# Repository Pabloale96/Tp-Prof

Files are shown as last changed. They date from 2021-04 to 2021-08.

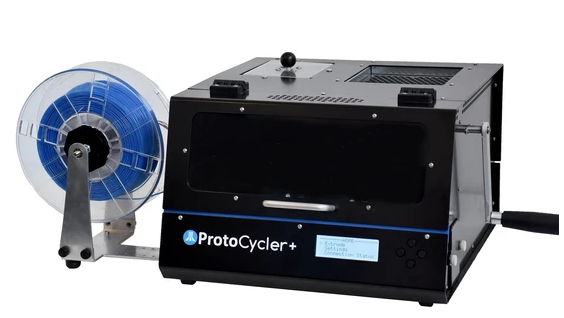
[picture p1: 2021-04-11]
Informacion-Equipos-Comerciales/redetec/producto.png

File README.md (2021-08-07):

# Trabajo Profesional

Este trabajo consiste en realizar una excursora de plastico, principalmente del polimero PLA que es el mas usado en las impresoras 3D. Dicho polimero empiza a ser moldiable en una temperatura entre los *80 ºC* a *110 ºC*, para realizarlo vamos a realizar un control de temperatura sobre el extrusor para mantener una temperatura en ese rango. Vamos a considerar que el plastico ingresa en trozos iguales y de un tamaño entre *1.5 mm* a *2.5 mm* **(Le tire para tirar)**. 

## Distribución del git (carpetas):

    - **Archivo README.md**: es lo que lees en el git, siempre que agregues alguna informacion intenta de agregarlo aca.
    - **Bibliografia**: carpeta en donde guardaremos toda la informacion de otros utilizada para poder realizar el proyecto, es importante agregar todo lo que usamos hasta los link de iterner, despues en el informe final seguro haya que agregarlo, creare un archivo de *link.txt* para todo el tema de los links, si se puede agregar una mini descripcion.
    - ** Diseño **: esta carpeta se divide entre las diferentes etapas del proyecto siguiendo la forma
    - ** Etapa1-Extrusora**: carpeta que contiene la informacion sobre la etapa de la extrusora, se divide de la forma:
        - ** Componentes **: aca se colocara la informacion de los componentes mecanicos y electricos usado en la etapa
        - ** Diseño **: carpeta que contiene el todos los datos sobre el diseño de la etapa, como por ejemplo, circuitos, modelos 3D, plano
        - ** Firmware **: carpeta que contiene el codigo del microcontrolador de la etapa
    - ** Etapa2-PID-Temp**: carpeta que contiene la informacion sobre la etapa del control de temperatura, se divide de la forma:
        - ** Componentes **: aca se colocara la informacion de los componentes mecanicos y electricos usado en la etapa
        - ** Diseño **: carpeta que contiene el todos los datos sobre el diseño de la etapa, como por ejemplo, circuitos, modelos 3D, plano
        - ** Firmware **: carpeta que contiene el codigo del microcontrolador de la etapa
    - ** Etapa3-Enfriamiento**: carpeta que contiene la informacion sobre la etapa del enfriamiento a la salida de la extrusora, se divide de la forma:
        - ** Componentes **: aca se colocara la informacion de los componentes mecanicos y electricos usado en la etapa
        - ** Diseño **: carpeta que contiene el todos los datos sobre el diseño de la etapa, como por ejemplo, circuitos, modelos 3D, plano
        - ** Firmware **: carpeta que contiene el codigo del microcontrolador de la etapa
    - ** Etapa4-Diametro-Medicion**: carpeta que contiene la informacion sobre la etapa de medicioin de diametro sin contacto, se divide de la forma:
        - ** Componentes **: aca se colocara la informacion de los componentes mecanicos y electricos usado en la etapa
        - ** Diseño **: carpeta que contiene el todos los datos sobre el diseño de la etapa, como por ejemplo, circuitos, modelos 3D, plano
        - ** Firmware **: carpeta que contiene el codigo del microcontrolador de la etapa
    - ** Etapa5-Bobinado**: carpeta que contiene la informacion sobre la etapa del bobinamo del material reciclado, se divide de la forma:
        - ** Componentes **: aca se colocara la informacion de los componentes mecanicos y electricos usado en la etapa
        - ** Diseño **: carpeta que contiene el todos los datos sobre el diseño de la etapa, como por ejemplo, circuitos, modelos 3D, plano
        - ** Firmware **: carpeta que contiene el codigo del microcontrolador de la etapa
    - ** Etapa6-Tablero**: carpeta que contiene la informacion sobre la etapa del diseño del tablero para el uso de la maquina, se divide de la forma:
        - ** Componentes **: aca se colocara la informacion de los componentes mecanicos y electricos usado en la etapa
        - ** Diseño **: carpeta que contiene el todos los datos sobre el diseño de la etapa, como por ejemplo, circuitos, modelos 3D, plano
        - ** Firmware **: carpeta que contiene el codigo del microcontrolador de la etapa
    - ** Factibilidad-Gestion-Tareas ** : carpeta que presenta el analisis realizado del mercado junto con las cantidad de hora de cada tarea, dentro se devide en la parte de factibilidad y la parte de tareas.
    - ** Firmware **: carpeta donde presenta el codigo unido de las diferentes etapas.
    - ** Informacion-Equipos-Comerciales **: carpeta para guardar la informacion sobre los equipos comerciales que se encuentra en el mercado actualmente (competenecia)
    - ** Investigacion **: carpeta para guardar la investigacion sobre las normas necesarias para el comercio del producto
    - ** Reuniones **: carpeta donde se guardan las notas de las reuniones que se tuvieron con los tutores. Dentro se dividira en carpetas con un nombre año-mes-dia que se obtuvo la reunion

# Overleaf:
    -link : https://www.overleaf.com/project/60784f0907656d9d9f60732d

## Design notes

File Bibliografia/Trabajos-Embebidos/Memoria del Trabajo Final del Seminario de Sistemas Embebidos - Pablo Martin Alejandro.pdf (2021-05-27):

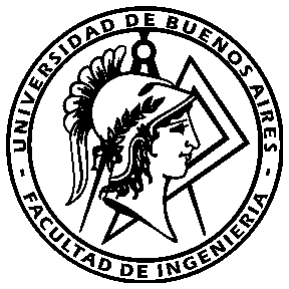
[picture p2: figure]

UNIVERSIDAD DE BUENOS AIRES Facultad de Ingeniería
Seminario de Sistemas Embebidos

Memoria del Trabajo Final:

## Reciclador PLA

Autor:

## Sr. Pablo Martín Alejandro

Legajo: 98.021

Este trabajo fue realizado en las Ciudad Autónoma de Buenos Aires, entre agosto y diciembre de 2019.

Memoria del Trabajo Final del Seminario de Sistemas Embebidos Sr. Pablo Martín Alejandro

## RESUMEN

En este trabajo se realizó el diseño y la fabricación de una recicladora de plástico PLA para el uso en la impresión 3D. La recicladora consiste en un sensor de temperatura con un control de completar, junto con un display para mostrar por pantalla un menú. También se agregó un módulo de wifi junto con un diseño de pagina web para el manejo de la misma. Se pudo aprovechar la herramienta de Yakindu para la realización del trabajo.

Martín Alejandro

## Índice General

Registro de versiones | 4

Introducción General

1.1 Descripción del proyecto | 5
Introducción Específica | 7
2.1 Descripción del hardware | 7
2.1.1 Plataforma de desarrollo | 8
2.1.2 Módulo Wifi | 9
2.1.3 Display y encoder | 10
2.1.4 Resistencia Cartucho | 10
2.1.5 Otros | 11
2.2 Descripción del software | 11
Diseño e Implementación | 13
3.1 Análisis del hardware | 13
3.1 Análisis del software | 15
Ensayos y Resultados | 19
4.1 Pruebas funcionales del hardware | 19
4.1 Pruebas funcionales del software | 19
4.1 Union del proyecto | 20
Conclusiones | 22
5.1 Conclusiones generales | 22
5.2 Próximos pasos | 22
Bibliografía | 23

Martín Alejandro

## Registro de versiones

Revisión | Cambios realizados | Fecha
1.0 | Creación del documento | 5/12/2019
1.1 | Correcciones del presente informe | 9/12/2019
1.2 | Continuación de correcciones | 10/12/2019
1.3 | Correcciones | 11/12/2019

Martín Alejandro

## CAPÍTULO 1

## Introducción general

### 1.1 Descripción del trabajo

El esquema general un reciclador de plástico PLA se puede observar en la figura 1.1. El reciclador tiene diferentes partes bien diferenciadas, como un calentador para lograr una temperatura fija en un extremo de la máquina. Otra parte es el motor de continua encargado de entregar el torque a una mecha de madera para trasladar el plástico. Por otro, lado, se usa un cilindro con una mecha de madera para trasladar el plástico depositado en la tolva, y con el torque de motor de continua se traslada al extremo caliente del cilindro. Por último, se coloca un pico fino para dar un diámetro al filamento que se extrae.

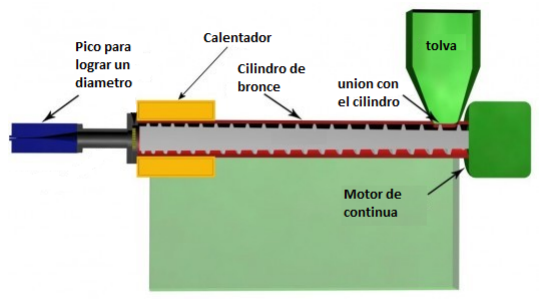
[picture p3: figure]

Figura 1.1: Partes del reciclador PLA

La recicladora PLA tiene ventajas tanto para las industrias como para personas en sus hogares. También ayuda para reducir desechos en el medio ambiente. Puede usarse tanto en la industria como en una casa, ya que recicla las partes de plástico que se consideran desecho, reduciendo la basura generada y lograr ahorrar dinero en materiales.

Martín Alejandro

El diagrama en bloques del sistema se muestra en la figura 1.2.

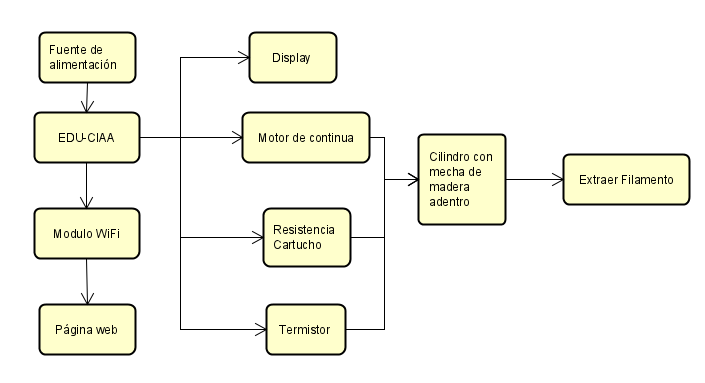
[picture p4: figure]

Figura 1.2: Diagrama de bloques del sistema.

Martín Alejandro

## CAPÍTULO 2

## Introducción específica

### 2.1 Descripción del hardware

En esta sección, se explica la fabricación del hardware del equipo. Para la realización del trabajo se colocó una mecha de madera (con la punta cortada) dentro de un cilindro hueco de bronce de igual diámetro para evitar que la mecha se atorre a la hora de trasladar el plástico (en nuestro caso se pidió utilizó un cilindro y una mecha de un diámetro de ⅝ de pulgada).

Se necesito fijar la estructura por el torque que generaba el motor sobre la misma. Se usaron para esto tornillos y una madera. Se utilizó un motor de continua para generar un torque sobre la mecha de madera, con esto se logra trasladar el plástico desde un punto A a un punto B.

Se conectó un driver (entre el motor y la EDU-CIAA) para el manejo de la corriente que necesita el motor de continua. Para el sensado de temperatura, se usó un termistor que varía su resistencia dependiendo de la temperatura. Para poder medir una temperatura de 200 ºC, se colocó una resistencia aproximada al valor del termistor en esa temperatura (500 ohm). En el programa, se empieza a medir a partir de 150 ºC que es lo que llega a medir el termistor con una resistencia aproximada de 500 ohm conectada en serie. Se colocó un display conectado a la EDU-CIAA donde se muestra el menú del equipo (para setear la temperatura y mover el motor a partir de un encoder). También se le agregó un módulo de WiFi donde se programa una página web para setear y mostrar los valores de temperatura y revisar si el motor de continua está prendida o no.

Para la colocación del plástico, se usó un material impreso por una impresora 3D al igual que la pieza que una el motor con la mecha y la que fija el motor a la madera. Todo lo mencionado anteriormente se observa conectado en la figura 2.1

Martín Alejandro

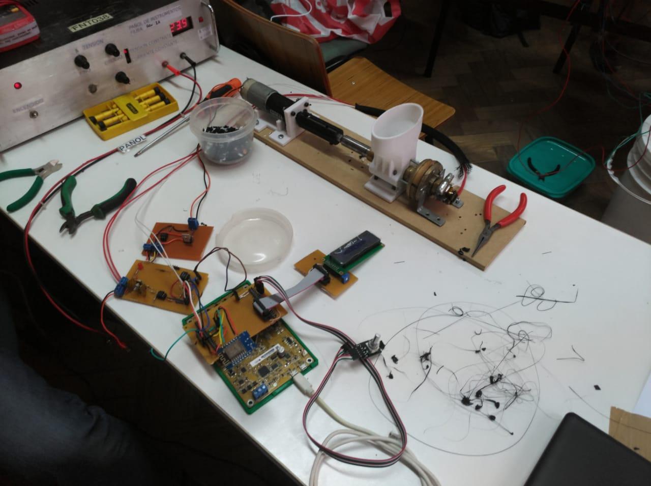
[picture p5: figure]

Figura 2.1:Reciclador Pla terminado.

### 2.1.1 Plataforma de desarrollo

La figura 2.2 muestra la placa EDU-CIAA la cual fue utilizada para la comunicación entre los diferentes equipos para el presente trabajo. La misma presenta toda la información de forma libre en internet en su página oficial [2]. Presenta un conversor DAC y un ADC, en este trabajo se realizó una medición usando el ADC de la placa, luego se comunicó con el puerto serie.

Martín Alejandro

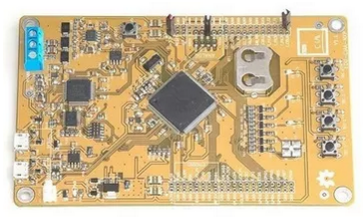
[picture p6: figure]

Figura 2.2: Placa EDU-CIAA.

### 2.1.2 Módulo de WiFi

Para la comunicación con la página web, se usó un módulo WiFi. En la figura 2.3 se observa dicho módulo, su modelo es el ESP8266. El mismo se comunica por puerto serie a la plataforma de desarrollo y luego actualiza los datos de la página web.

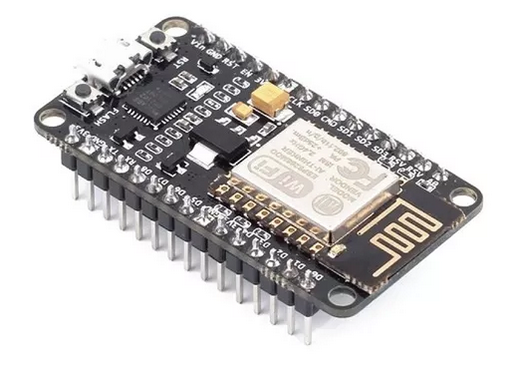
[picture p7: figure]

Figura 2.3: Módulo Wifi

Martín Alejandro

### 2.1.3 Display y Encoder

Para el manejo del trabajo, se realizó un menú para controlar los diferentes parámetros. Se usó un display común para visualizar dicho menú y un encoder común para controlar el menú. Las figura 2.4 y 2.5 muestran los dispositivos.

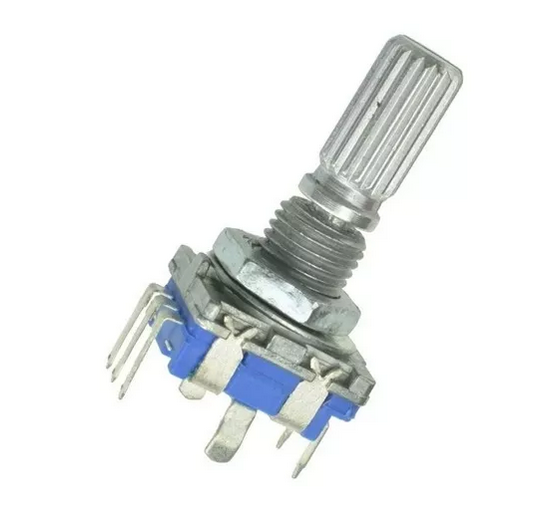
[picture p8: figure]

Figura 2.4: Encoder.

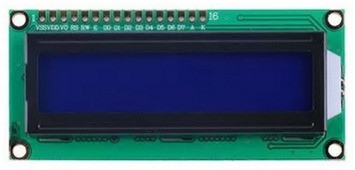
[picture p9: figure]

Figura 2.5: Display.

### 2.1.4 Resistencia cartucho

Para lograr calentar el extremo del tubo, se utilizó una resistencia cartucho conectada a 24 V. Se usó el PWM de la placa EDU-CIAA para reducir el valor rms de tensión sobre la

Martín Alejandro

resistencia cartucho (si se reduce la tensión calienta menos) para controlar la temperatura. La resistencia se muestra en la figura 2.6.

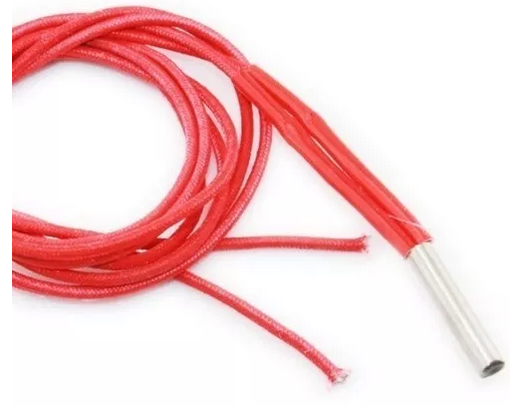
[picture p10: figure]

Figura 2.6: Resistencia Cartucho.

### 2.1.5 Otros

La medición de la temperatura se realizó con un termistor (resistencia que varía con la temperatura) ntc de valor nominal 100 kohm. Otros elementos fueron transistores para los circuitos usados como driver y controlador de la resistencia cartucho.

### 2.2 Descripción del software

El software se diseñó a partir de la herramienta de Yakindu, la cual permite usar un diagrama UML de máquinas de estado y luego genera un código que corresponde al diagrama realizado[1]. La idea lógica del programa es realizar un control de temperatura para lograr establecer un valor de 200 ºC en un extremo de la máquina, luego decirle al reciclador de mover el motor en para llevar el plástico al extremo caliente. El programa manda los datos a través de un módulo de Wifi a una página web mencionada anteriormente (también se puede setear la temperatura y activar el movimiento de motor desde ahí).

Se agregó un display por si el módulo o la página web no funciona para activar la máquina, el display muestra un menú que tiene la configuración de temperatura y motor. También tiene un menú de WiFi que muestra la IP de la página web.

Martín Alejandro

La figura 2.7 muestra la lógica del programa implementado.

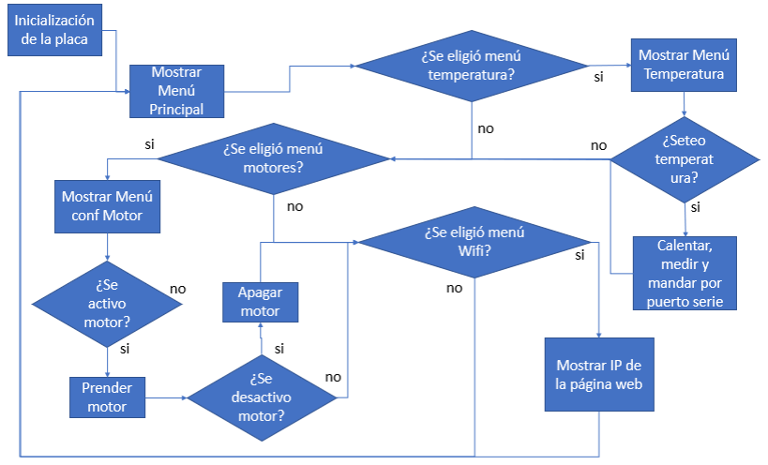
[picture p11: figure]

Figura 2.7 : Diagrama lógico del programa.

Martín Alejandro

## CAPÍTULO 3

## Diseño e implementación

### 3.1 Análisis del hardware

A la hora de realizar el trabajo, se consideró como principal problema la estructura por su partes mecánicas y la precisión milimétrica, la velocidad del movimiento del motor y la instalación de una resistencia cartucho junto con el termistor. Esta última, se debe a que la resistencia cartucho está a una temperatura mayor y para lograr medir la temperatura del cilindro, se necesita que el termistor este distante a la resistencia cartucho pero en contacto con el cilindro.

Para la conexión del motor, se usó un driver para aumentar la corriente que entrega la EDU-CIAA sobre el motor (usando una fuente de tensión de 24V). En la figura 3.1, se observa el circuito utilizado como driver.

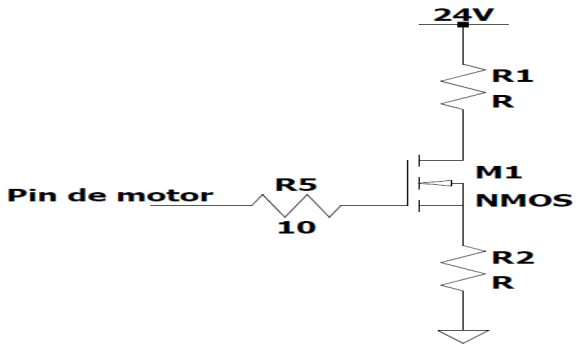
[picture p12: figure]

Figura 3.1: Circuito driver para el motor de excursión.

Por otro lado, para el control de la resistencia cartucha se usó el circuito de la figura
3.2. En la figura 3.3, se muestra el circuito usado para la medición de la temperatura a

Martín Alejandro

través del termistor, teniendo en cuenta la ecuación de resistencia de un termistor, presentada a continuación como:

R = R | | (3.1)
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
en donde se puede despejar la temperatura. Resolviendo el circuito de la figura 3.3 se puede llegar a un valor de R como:

R = 500 oℎm | , | (3.2)

V

CC−V
ADC
V
ADC
usando la EDU-CIAA se mide la tensión sobre el pin de ADC y luego se despeja la resistencia R, luego se puede despejar la temperatura teniendo en cuenta los parámetros dado por el fabricante[4]. Realizando todo lo mencionado, se puede aproximar la relación tensión temperatura con la siguiente fórmula:
T = | .

129.3*1000+V
ADC

*34.5

1000

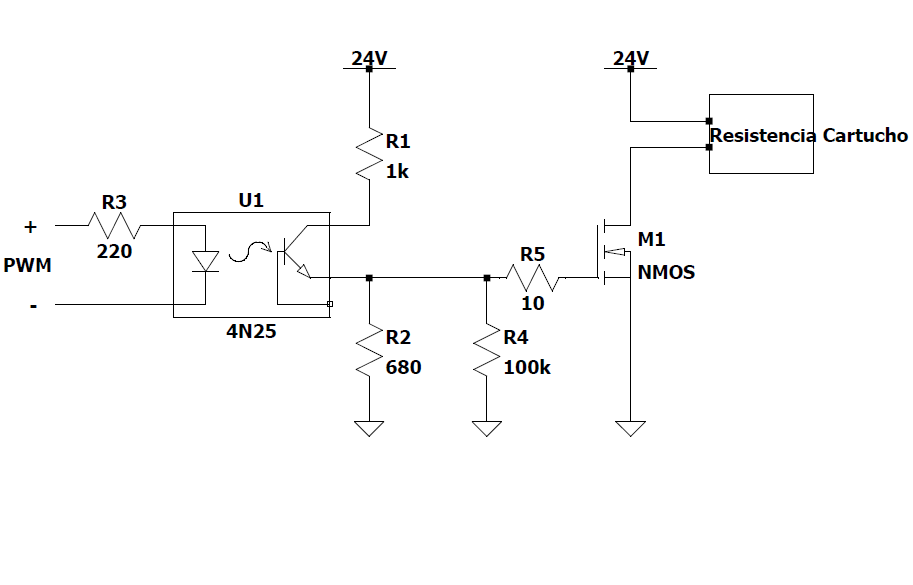
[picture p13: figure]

Figura 3.2: Circuito de control de la resistencia Cartucho.

Martín Alejandro

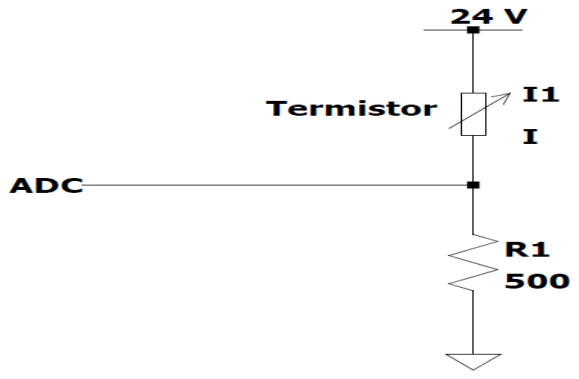
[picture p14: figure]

Figura 3.3: Circuito para la medición de la temperatura.

### 3.2 Análisis del software

El software fue generado a partir un diagrama UML de estados a partir de la herramienta de Yakindu. Por motivos de complejidad, se decidió dejar el link del repositorio de GitHub[3] usado para el trabajo práctico ya que el diagrama de estados es demasiado grande para mostrar una imagen.

Igualmente, se mostrará la complejidad del diagrama de estados con las figuras 3.4 hasta la figura 3.9 . El archivo prefix usado en Yakindu es demasiado largo para mostrar en una imagen por lo que no se incluye.

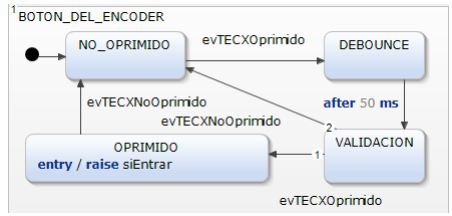
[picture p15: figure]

Figura 3.4: Diagrama de estados para controlar el botón oprimido.

En la figura 3.4, se muestra un diagrama de estado para la validación de un pulsador (el presente en el encoder) .

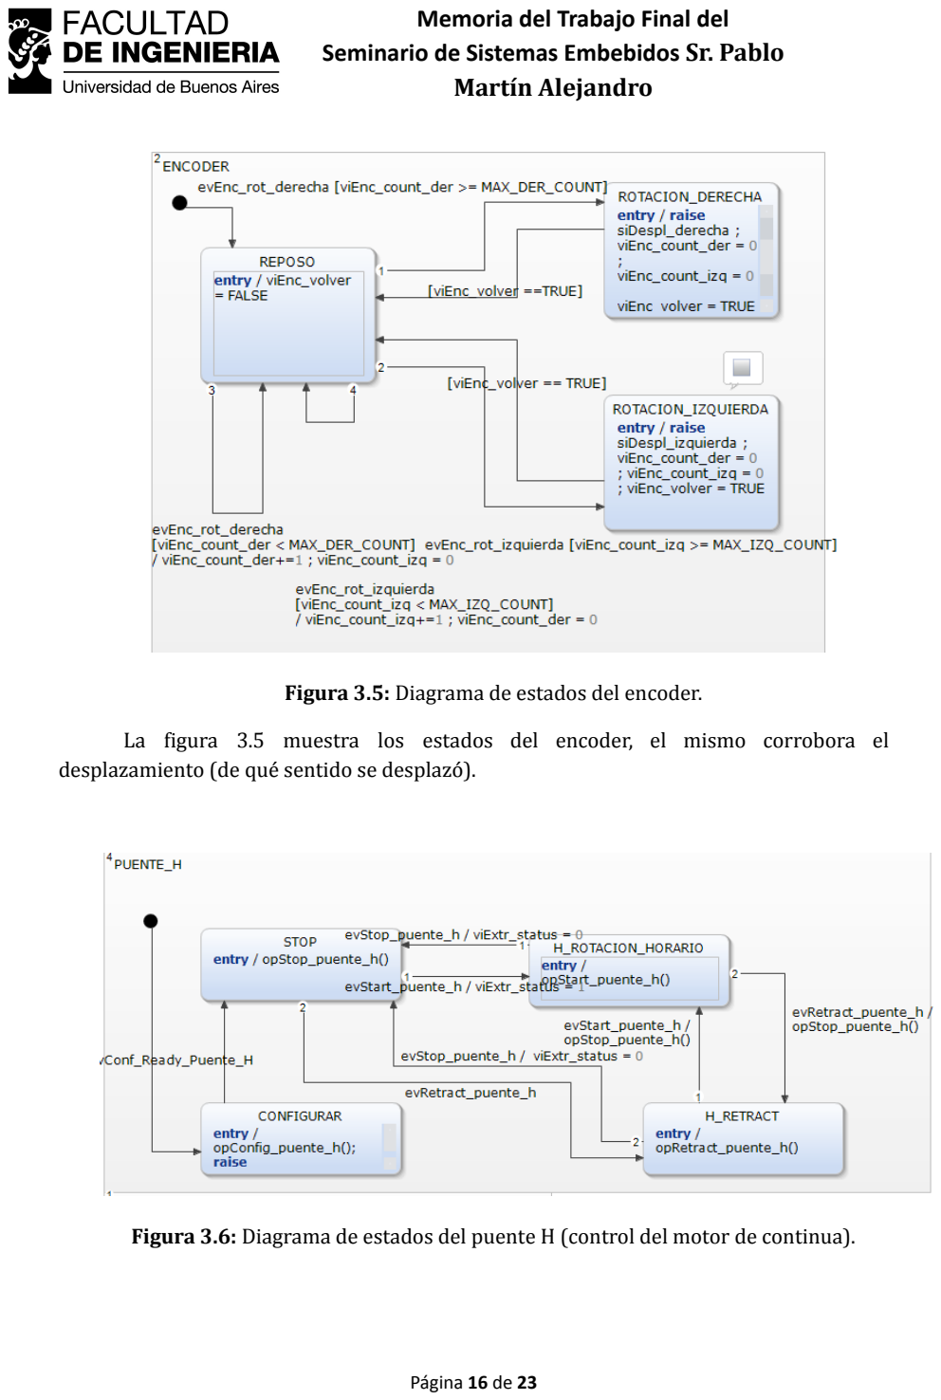
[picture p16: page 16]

Martín Alejandro

Figura 3.5: Diagrama de estados del encoder.

La figura 3.5 muestra los estados del encoder, el mismo corrobora el desplazamiento (de qué sentido se desplazó).

Figura 3.6: Diagrama de estados del puente H (control del motor de continua).

Martín Alejandro

El control del motor se realiza con el diagrama de estado de la figura 3.6. Se observa 4 estados, en donde el estado inicial es de la configuración los pines gpio de la EDU-CIAA. Los otros 3 estados setean el estado del motor (apagado, encendido o reversa).

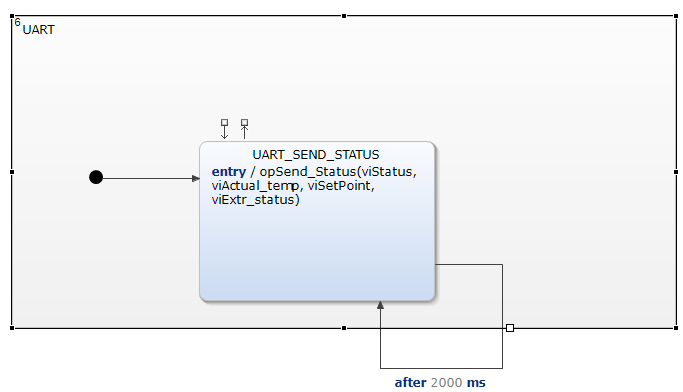
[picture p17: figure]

Figura 3.7: Diagrama de estados del envío de mensajes por UART.

El envío por UART presenta un solo estado que se repite cada 2 segundos, esto se observa en la figura 3.7.

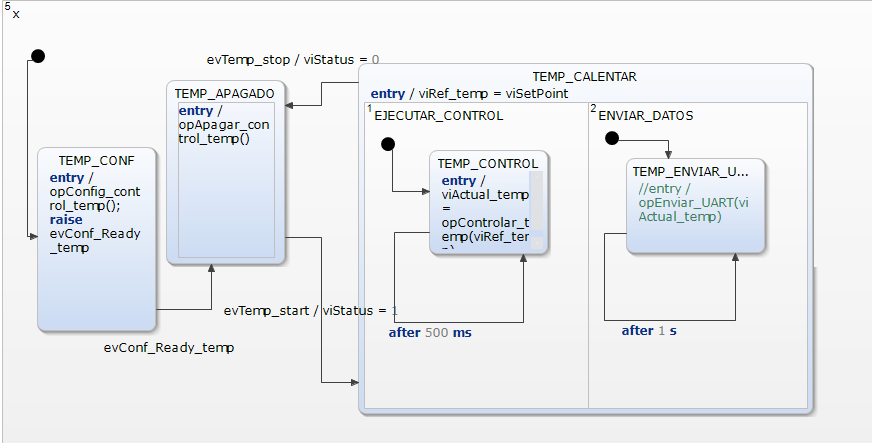
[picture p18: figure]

Figura 3.8: Diagrama de estados sensado y control de temperatura.

Para el control de temperatura se observa un estado inicial que sirve para la configuración del ADC. Luego, se mantiene en un ciclo entre los estados de apagado de la

Martín Alejandro

temperatura (al inicio la máquina no realiza nada) y un estado compuesto que realiza un control de temperatura y envía los datos por puerto serie.

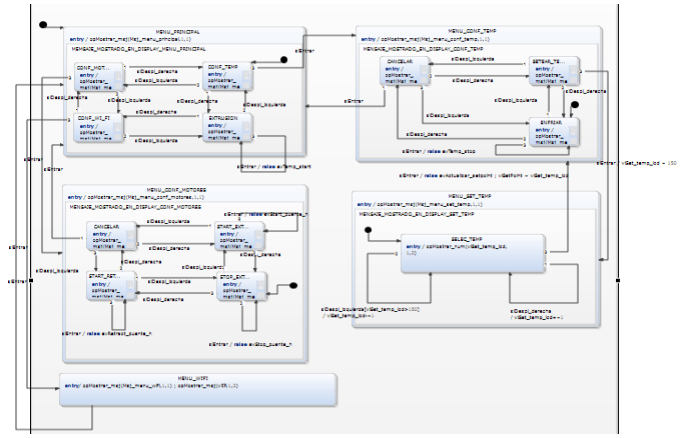
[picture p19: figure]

Figura 3.9: Diagrama de estados del menú.

Por último, en la figura 3.9 se observa los estados del menú realizado. El mismo consta con un menú principal que se divide en 3 submenus.

Martín Alejandro

## CAPÍTULO 4

## Ensayos y resultados

### 4.1 Pruebas funcionales del hardware

La primera prueba realizada sobre el trabajo es comprobar el funcionamiento correcto de la partes mecánicas armadas. Para eso, se armó el producto y manualmente se revisó el funcionamiento de la mecánica.

La segunda prueba incluyó agregar el motor de continua para poder revisar la velocidad y el movimiento a esa velocidad. En esta prueba, se encontró un problema con el torque generado por el motor, el mismo provocaba que la piezas de plástico se rompieran por un giro inesperado sobre ellas (las piezas giraban con la mecha). La solución a este problema fue atornillar las piezas a un bloque de madera.

Por último, se probó el correcto calentamiento del extremo del cilindro revisando el circuito mencionado en la figura 3.2. Se colocó la resistencia cartucho y se utilizó una señal de pwm constante para controlar a qué temperatura aumenta. Luego, se varió el pwm para ver cómo modifica la temperatura. La figura 2.1 muestra la mecánica del reciclador completo, mientras la figura 4.1 muestra una de las uniones de la mecánica (la mecha de madera con el motor de continua).

### 4.2 Pruebas funcionales del software

La primera prueba tenía que ver con el control y sensado de la temperatura. Para eso se midió la temperatura a través del ADC (como se mencionó anteriormente) y luego se aplicó una planta para lograr aumentar la temperatura al menor tiempo posible sin pasarse del valor establecido. Con la medición de la temperatura mencionada anteriormente, se mandó el valor al puerto serie para visualizar en la computadora.

La segunda prueba era controlar que el valor de la temperatura medida con el termistor es la equivalente en la punta. Para eso, se usó un multímetro con una termocupla en sus terminales (con la capacidad de medir grados ºC) y se revisó que el valor del multímetro sea el mismo con el medido en el termistor. La figura 4.2 muestra lo que se recibió la computadora por puerto serie en una terna donde indica si la temperatura está prendida (ON/OFF). El segundo valor indica la temperatura medida por

Martín Alejandro

el termistor (un valor numérico). El último carácter indica la temperatura a la que se tiene que llegar (otro valor numérico). La terna está separado por el caracter ‘ , ’.

Por último, se probó el módulo de WiFi desconectado con el resto de las placa y controlamos si actualizaba la página web. Para comprobar el correcto funcionamiento, se transmitió por puerto serie los valores random hacia el módulo de Wifi y luego se actualizaba la página web.

### 4.3 Unión de las partes del reciclador

La última prueba de todas fue comprobar el conjunto de las partes de la máquina. Se comprobó, principalmente, las partes por separados. Realizando la unificación de todas las partes y se logrando reciclar plástico triturado. La figura 4.3 muestra el filamento extraído por el reciclador.

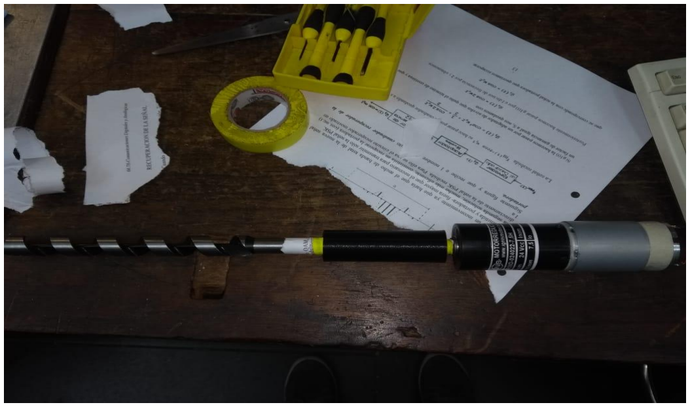
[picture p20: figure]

Figura 4.1: Unión de la mecha con el motor de continua.

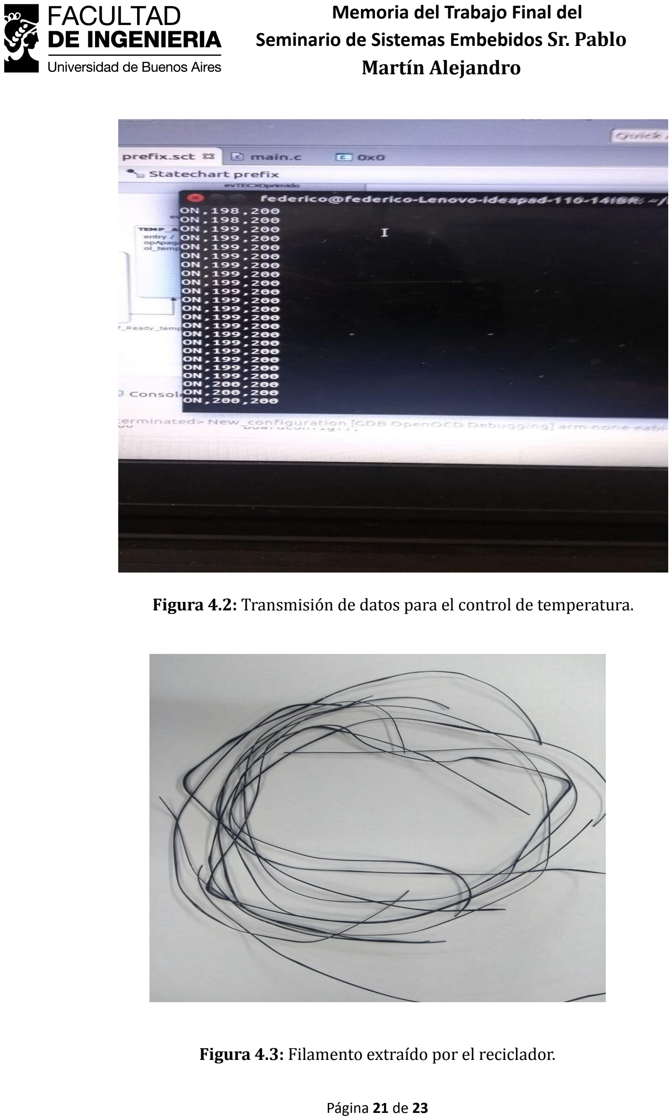
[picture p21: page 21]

Martín Alejandro

Figura 4.2: Transmisión de datos para el control de temperatura.

Figura 4.3: Filamento extraído por el reciclador.

Martín Alejandro

## CAPÍTULO 5

## Conclusiones

### 5.1 Conclusiones generales

La principal conclusión se consigo en la facilidad de hacer diagramas de estados a través de la herramienta Yakindu, la misma define estados, variables y operaciones que luego en el código se editan para realizar la tarea que uno decide hacer (creo funciones con sus argumentos y variables globales que luego en el código se puede definir dichas funciones).

Otra conclusión importante es la división de tareas formado por el equipo de trabajo, sin una planificación (informe de planificación) previo nos dio la pauta para lograr el trabajo en el tiempo determinado, o por lo menos lograr una presentación prolija y tener documentación sobre el trabajo.

Finalmente, realizar una tarea de mecánica avanzada puede generar problemas a futuro si es que no se tuvo en cuenta en el informe de planificación del trabajo com un riesgo posible.

### 5.2 Próximos pasos

El trabajo tiene varias mejoras, en esta sección se mencionan algunas:

- Lograr un diámetro constante a través de una rueda hueca y una rueda plana para darle forma de cilindro al filamento de salida con un diámetro determinado.
- Enrollar el filamento de salida del trabajo en un cilindro de plástico para luego usar directamente con la impresora 3D.
- Conseguir una trituradora de plástico para lograr problema de tamaño
- Enfriar el filamento de salida a una velocidad que permite enrollar el filamento a la salida del proceso.
- Diseñar una fuente de tensión continua para conectar a la red directamente.

Martín Alejandro

## Bibliografía

[1] YAKINDU(2016, Jun 26). YAKINDU Documentation [Online]. Available: https://www.itemis.com/en/yakindu/state-machine/
[2] Proyecto CIAA (2016, Jun 26). EDU-CIAA-NXP [Online]. Available: http://www.proyecto-ciaa.com.ar/devwiki/doku.php
[3] Repositorio del trabajo final usado. Available:

https://github.com/Federiconunezfrau/Reciclador_PLA.git

[4] Hoja de datos del termistor. Available:

Buscar en google “NTC Thermistor Farnell datasheet” y descargar el pdf

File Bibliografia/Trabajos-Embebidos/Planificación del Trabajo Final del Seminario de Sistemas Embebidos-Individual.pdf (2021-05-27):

### Plan del Trabajo Final de Sistemas Embebidos Pablo Martin Alejandro-Padrón 98.021

# Reciclador de PLA

### Autores

## Pablo Martin Alejandro-Padrón 98.021

### Fecha:

## 2do cuatrimestre 2019

### Tabla de contenido

Registro de cambios | 3
Descripción técnica-conceptual del proyecto a realizar | 4
Acta de constitución del proyecto | 5
1. Propósito del proyecto | 6
2. Alcance del proyecto | 6
3. Supuestos del proyecto | 6
4. Requerimientos | 6
5. Entregables principales del proyecto | 7
6. Desglose del trabajo en tareas | 7
7. Diagrama de Gantt | 7
8. Gestión de riesgos | 8
9. Gestión de la calidad | 9

### Registro de cambios

Revisión | Cambios realizados | Fecha
1.0 | Creación del documento y firma del Acta de Constitución | 17/09/2019
1.1 | Completación de la descripción técnica-conceptual del proyecto | 17/9/2019
1.2 | Realización de las secciones 1,2,3,4,5,6,y mitad del 8 | 24/9/2019
1.3 | Correcciones de las secciones mencionadas y realización de las secciones 7,8 y 9. | 30/9/2019
1.4 | Correcciones del informe en general | 1/10/2019

### Descripción técnica-conceptual del proyecto a realizar

En este proyecto se propone construir un dispositivo automático que, a partir de restos plásticos de impresiones 3D (material PLA), produzca rollos de filamento nuevos que se puedan usar para imprimir nuevas piezas.

El hecho de poder generar filamento para impresión 3D a partir de restos de plástico tiene como motivación:

- El ahorro en el costo de compra de rollos de plástico nuevos.
- La contribución al cuidado del medio ambiente, dándole un nuevo uso a estos plásticos que fueran a ser desechados.

Para poder explicar el proyecto, se muestra en la Figura 1, las partes que lleva un reciclador PLA. Se tiene un Hopper para colocar el plástico a reciclar (el cual tiene que estar triturado), un Scew para trasladarlo hasta el Heater que presenta un Breaker plate para darle la forma correspondiente al plástico,.l Heater es el encargado de calentar el PLA hasta una temperatura que sea moldeable el mismo (la temperatura debe estar entre los 190ºC y 220ºC). Luego se da la forma de un cilindro con un diámetro de 1.75 mm (estándar que usan las impresoras 3D).

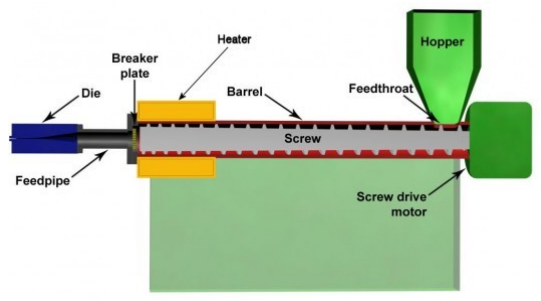
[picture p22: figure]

Figura 1.Partes del reciclador PLA

El proceso de extrusión se puede observar en la Figura 2. El mismo se considera un Extruner que sería la parte mecánica mostrada en Figura 1, a la salida del mismo un proceso de enfriado para poder dejar el plástico firme. Luego se realiza un pulido del mismo a través del Puller y por último se enrolla el filamento en un cilindro en la parte de Cutting/Removal.

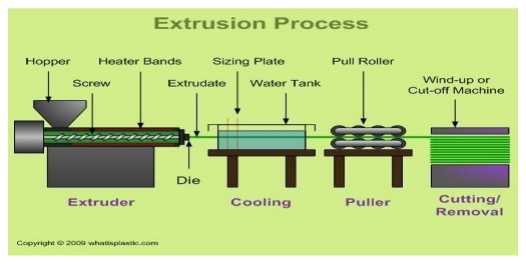
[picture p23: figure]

Figura 2:Proceso de excursión.

Para realizar el proyecto, se utiliza la placa de la EDU-CIAA para realizar el control de temperatura del dispositivo. Además se comunica el microcontrolador de la placa con un driver de motor para manejar tanto el motor que se utiliza para el Screw como el ventilador que enfría el plástico a la salida del extrudate. Para mostrar el uso de la EDU-CIAA se realizó un diagrama en bloques que se muestra en la Figura 3, donde el motor corresponde a la traslación del plástico del punto inicial hasta el punto donde se moldea el plástico, es decir, hasta el heater bands el cual se encuentra representado con el bloque “control de temperatura”. A la salida del mismo, se va a encontrar el filamento a una temperatura aproximadamente de (190-220)ºC estable en un rango de 5ºC para lograr moldear el plástico PLA, por lo tanto se coloca un ventilador y un motor paso a paso para enfriar el filamento y recolectar en forma de cilindro como se mostró anteriormente.

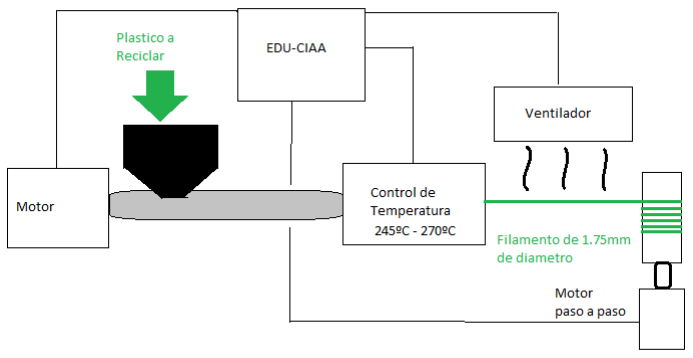
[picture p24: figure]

Figura 3:Diagrama de Bloques.

Con todo este sistema, se cumple el objetivo de lograr una recicladora de plastico PLA. Si sobra el tiempo se podría mejorar el equipo con:

1. Agregar display para marcar la temperatura.
2. Controlar diferentes temperaturas (esto lograría una gran mejora, ya que se podría utilizar para diferentes tipos de plástico, como el ABS).
3. Agregar una trituradora con un sistema de seguridad propio, ya que el plástico tiene que estar triturado para colocar en el sistema.

### Acta de constitución del proyecto

Buenos Aires, 24 de septiembre de 2019

Por medio de la presente se acuerda con el Alejandro, Pablo Martín que su Trabajo Final del Seminario de Sistemas Embebidos se titulará “Reciclador Pla”, consistirá esencialmente en el prototipo preliminar de un control de temperatura con un rango de 5ºC con un sistema embebido, y tendrá un presupuesto preliminar estimado de 140 hs de trabajo y $30000, con fecha de inicio lunes 14 de octubre de 2019 y fecha de finalización miércoles 4 de diciembre de 2019.

Se adjunta a esta acta la planificación inicial.

Ariel Lutenberg
Profesor Adjunto del Seminario de Sistemas Embebidos

### 1. Propósito del proyecto

El propósito de este proyecto es el diseño y la implementación de un “Reciclador PLA”, el cual cumple con la función de tomar plástico desechable y transformarlo en filamento para la impresión 3D que cada día se utiliza más. Una importancia del reciclado del plástico es evitar generar basura para mejorar el medio ambiente, aparte se podría ahorrar dinero en los filamentos generados.

### 2. Alcance del proyecto

El presente proyecto incluye las siguientes especificaciones:

- Terminar el proyecto antes de la fecha estipulada.
- Lograr generar un filamento utilizable para impresión 3D de diámetro de 1,75 mm.
- Conseguir un control de temperatura entre (190-220)ºC para el plástico PLA.
- Agregar opciones de conectividad: WiFi o Bluetooth.
- Seleccionar la temperatura a controlar con un sistema manual.
- Lograr operar motores para lograr una excursión del plástico.

El presente proyecto podría incluir (si alcanza el tiempo):

- Colocar un display para mostrar el control de temperatura y otros datos.
- Diseñar una aplicación para el uso del equipo a través de conectividad WiFi o Bluetooth.

El presente proyecto no incluye

- Una trituradora de plástico para evitar triturar aparte del mismo.

### 3. Supuestos del proyecto

Para el desarrollo del presente proyecto se supone

- El plástico que va a ser reciclado se encuentra en dimensiones pequeñas de tal forma que pueda pasar por el Screw de la máquina.
- Que el control de la temperatura debe ser estable por lo menos 3ºC del promedio del rango.
- A la salida el plástico se enfría por menos en 1 seg aproximadamente
- Un presupuesto de $30.000
- El plástico reciclado es del tipo PLA

### 4. Requerimientos

Aclaración: La prioridad de los requerimientos fue evaluado entre valores del 1 al 3 donde 3 significa una prioridad importante, 2 dice que es una prioridad intermedia y por último 1 aclara que la prioridad es menor.

1. Grupo de requerimientos asociado al control de temperatura
1.1. Lograr estabilidad en la temperatura con un rango de estabilidad de 5ºC. (Prioridad:2)
1.2. Controlar el valor de la temperatura establecida. (Prioridad:3)
1.3. Poder moldear el plástico para modificar su forma. (Prioridad:3)
2. Grupo de requerimientos asociado a la conexión
2.1. Conseguir una buena conexión con el dispositivo de control del equipo. (Prioridad:2)
2.2. Evitar interferencia entre diferentes equipos de control. (Prioridad:1)
2.3. Lograr una comunicación exitosa con los dispositivos utilizados (motor, display,celular,etc). (Prioridad:3)
3. Grupo de requerimientos referidos a la excursión del PLA
3.1. Trasladar el plástico desde el extremo de colocación al extremo de salida. (Prioridad:3)
3.2. Lograr enrollar el filamento de la salida en un cilindro para la colocación de la máquina de impresión 3D (generalmente viene en forma de cilindro).(Prioridad:1)
3.3. Poder controlar la velocidad de los motores para evitar problemas. (Prioridad:2)
4. Grupo de requerimientos referidos al display
4.1. Mostrar temperatura que se encuentra el equipo. (Prioridad:1)
4.2. Mostrar equipos conectados al equipo. (Prioridad:2)
4.3. Mostrar un menú donde tenga: “Seleccionar temperatura Manual”, ”Equipos Conectados”, etc.(Prioridad:2)
5. Grupo de requerimientos asociado al hardware del equipo
5.1. Que el equipo sea compacto para facilitar su movilidad. (Prioridad:2)
5.2. Especificar el lugar de colocación del plástico. (Prioridad:1)
5.3. Sistema de seguridad para evitar quemaduras al usuario del equipo. (Prioridad:3)

### 5. Entregables principales del proyecto

El proyecto deberá contar con un manual de uso para evitar confusiones al momento de maniobrar el equipo, el diagrama esquemático de las conexiones realizadas con el microcontrolador, un diagrama de instalación del mismo considerando que puede encontrarse errores de este estilo. Un informe final donde se especifica los requerimientos del equipo junto con las especificaciones del mismo, en este mismo se encuentra el código fuente utilizado para la realización de la tareas.

### 6. Desglose del trabajo en tareas

1. Grupo de tareas relacionadas con el Hardware (30hs)
1.1. Conseguir equipos para fabricar el Hardware.(1hs)
1.2. Fabricar la estructura base del mismo.(15hs)
1.3. Comprobar movilidad de los materias movibles.(14hs)
2. Grupo de tareas relacionadas con el Software (70hs)
2.1. Grupo de tareas relacionadas con la conexión de los equipo (40hs)
2.1.1. Lograr conexión con un dispositivo celular a través de Bluetooth o WiFi(20hs)
2.1.2. Lograr conexión con el micro y los diferentes dispositivos(motores,display,sensor de temperatura,etc)(20hs)
2.2. Grupo de tareas relacionadas con el control de temperaturas (30hs)
2.2.1. Lograr estabilidad sobre una temperatura.(15hs)
2.2.2. Mantener dicha temperatura en un rango.(15hs)
2.3. Grupo de tareas relacionadas con los motores (20hs)
2.3.1. Conseguir un velocidad adecuada para la excursión.(6:66 hs)
2.3.2. Poder enrollar el filamento de la salida.(6:66 hs)
2.3.3. Controlar el ventilador que funciona como cooler.(6:66 hs)
2.4. Grupo de tareas relacionadas con el display (20hs)
2.4.1. Creación del menú mencionado anteriormente.(10hs)
2.4.2. Mostrar temperatura del equipo.(5hs)
2.4.3. Mostrar la conexión con los equipos de control.(5hs)
3. Unificación del proyecto en general.(20hs)
4. Realización del informe de Avances.(Durante todo el proyecto 1 hs por semana estimada)
5. Redacción de la documentación. (10 hs)

### 7. Diagrama de Gantt

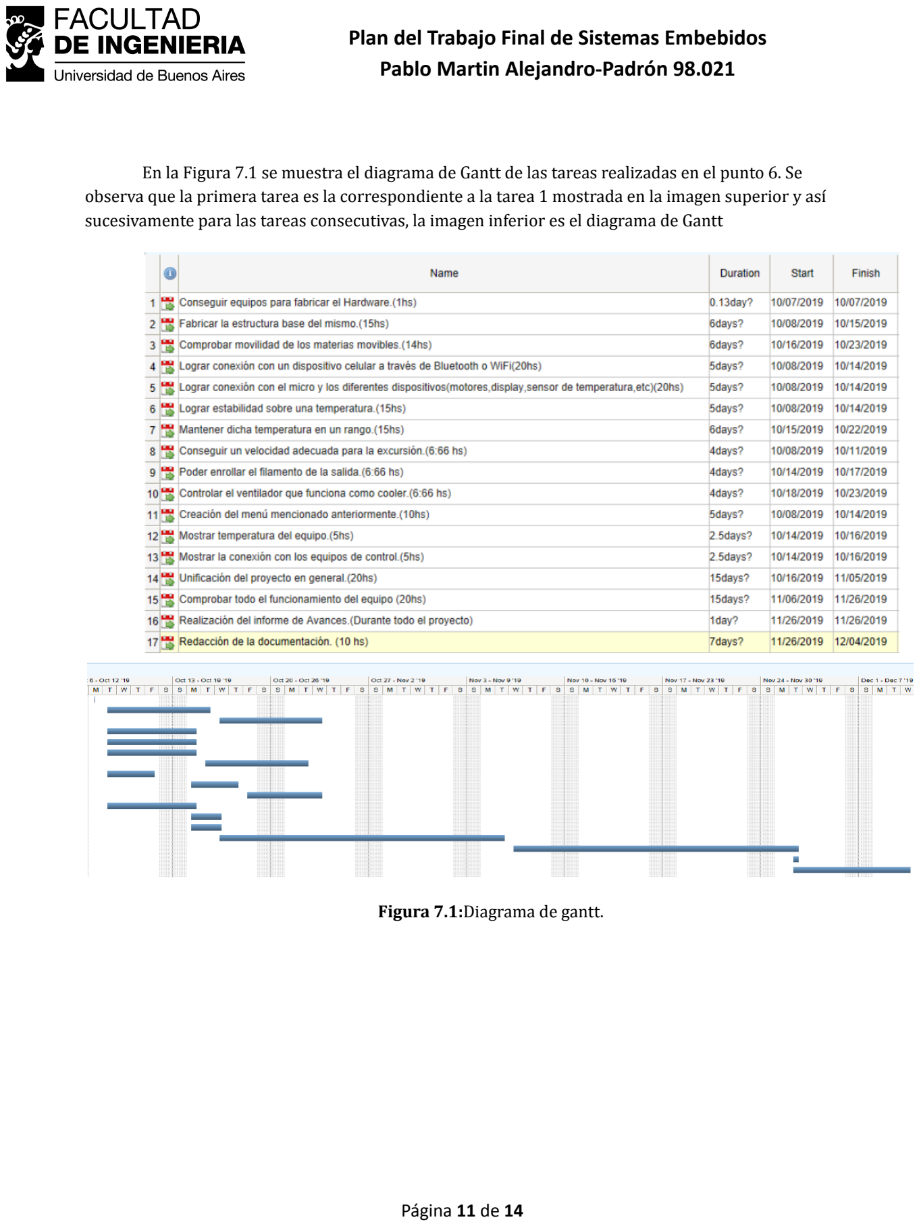
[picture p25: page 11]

En la Figura 7.1 se muestra el diagrama de Gantt de las tareas realizadas en el punto 6. Se observa que la primera tarea es la correspondiente a la tarea 1 mostrada en la imagen superior y así sucesivamente para las tareas consecutivas, la imagen inferior es el diagrama de Gantt

Figura 7.1:Diagrama de gantt.

### 8. Gestión de riesgos

a) Identificación de los riesgos:
i) Riesgo 1: problemas a conseguir las partes mecanicas como electricas, si nos atrasamos en conseguir algún material se atrasa todo el proyecto dicho tiempo hasta conseguirla.
■ Severidad (S): 10. Tiene una muy alta porque si ocurre tenemos que atrasar todo el proyecto mismo por no conseguir los materiales.
■ Probabilidad de ocurrencia (0): 2. Generalmente se puede conseguir los materiales por eso la probabilidad de ocurrencia es baja.
ii) | Riesgo 2: en la fabricación del hardware problemas de montaje o rupturas de
| elementos necesitados o diseño del mismo .
| ■ Severidad (S): 5.Presenta este número porque este riesgo se genera cuando
| nosotros lo hacemos y si se tiene cuidado se puede evitar pero se puede
| atrasar por un mal diseño del hardware, y había que volver a empezar.
| ■ Probabilidad de ocurrencia (0): 5. Como se mencionó en S se puede evitar si
| se toma un tiempo en pensar el diseño del hardware principalmente ya que un
| error ahí puede provocar que se retrase el proyecto.
iii) | Riesgo 3: problemas en la estabilidad de temperatura. Elevar la temperatura no es
| algo tan difícil pero el principal problema viene dado en mantener dicha temperatura.
| ■ Severidad (S): 3. Si no se consigue una estabilidad en un rango chico no es
| tan problema porque el plástico se moldea igual y se puede realizar la
| creación del filamento sin problemas.
| ■ Probabilidad de ocurrencia (0): 6. Puede ser que por un error de software
| no se consiga lo deseado pero también puede ser por un error de hardware.
iv) | Riesgo 4: mala comunicación con el dispositivo que controla al equipo
| ■ Severidad (S): 1. Si se logra hacer el seteo manual no es tan necesario el
| equipo maestro.
| ■ Probabilidad de ocurrencia (0): 7. Aparece por un error en la transmisión
| de la señal que puede ser que el equipo espera recibir en cierto baudios o pero
| el emisor manda en otro. También puede ser por problemas del canal de
| transmisión.
v) Riesgo 5: enfriamiento del filamento a la salida, el problema ocurre si se enfria
| demasiado rapido no se puede moldear en forma de cilindro, pero si no se enfríe
| demasiado rápido se estira el filamento deformando el diámetro del mismo.
| ■ Severidad (S): 10. Si no se respeta el diámetro el equipo no está cumpliendo
| el propósito para que uno lo diseñó.
| ■ Probabilidad de ocurrencia (0): 10. Generalmente este es un problema que
| ocurre en el diseño de este equipo, ya que se necesita una velocidad de
| enfriamiento gusta para poder generar los rollos de filamentos correctamente.

b) Tabla de gestión de riesgos: (El RPN se calcula como RPN=SxO)
Riesgo | Severidad | Ocurrencia | RPN | Severidad* | Ocurrencia* | RPN*
1 | 10 | 2 | 20 | - | - | -
2 | 5 | 5 | 25 | 3 | 5 | 15
3 | 3 | 6 | 18 | - | - | -
4 | 1 | 7 | 7 | - | - | -
5 | 10 | 10 | 100 | 5 | 5 | 25

Criterio adoptado:
- Se tomarán medidas de mitigación en los riesgos cuyos números de RPN sean mayores a 20.

Nota:
- Los valores marcados con (*) en la tabla corresponden luego de haber aplicado la mitigación.
c) Plan de mitigación de los riesgos que originalmente excedían el PRN máximo establecido:
I. Riesgo 2: El plan de mitigación en este riesgo es solo tener cuidado sobre el montaje del hardware a realizar, si se logra esto se puede evitar como se mencionó anteriormente.

Severidad (S): 3. Tiene una severidad menor, ya que si se toma precauciones se logra romper menos materiales posibles.

Probabilidad de ocurrencia (0): 5. Este número sale de que ninguno de los miembro del equipo sabe demasiada mecánica para evitar este riesgo.

II. | Riesgo 5: Este riesgo no se puede reducir demasiado con un plan de mitigación, porque depende de muchos factores. Lo que se realiza es agregar un cooler que podemos controlar la velocidad así podremos variar la velocidad de enfriado, con esto se busca la velocidad de enfriado óptima para generar el filamento en forma de cilindro.
| Severidad (S): 5. Logrando variar el cooler se puede reducir la severidad del riesgo, porque es tocar la velocidad del mismo para evitar que el filamento se rompa o se alargue.
| Probabilidad de ocurrencia (0): 5. Esto reduce la probabilidad de ocurrencia, porque haciendo cuentas se puede determinar la velocidad del cooler aproximada para evitar que ocurra el riesgo.

### 9. Gestión de la calidad

Para cada uno de los requerimientos del proyecto indique:

- Requerimiento 1: lograr un filamento para el uso de impresoras 3D con un diámetro aproximado a 1.75mm (con un rango de 10mm).
- Verificación: se generará un filtro de plástico de ese diámetro a la salida para lograr este requerimiento, como es moldeable el plástico quedará con el diámetro con el que salga.
- Validación: se realizara varios filamento de prueba para comprobar el diámetro del filamento.
- Requerimiento 2: lograr una temperatura estable entre (190-220)ºC
- Verificación: se colocara un sistema de control, con un transistor o un sensor de temperatura para poder saber cual es la temperatura.
- Validación: una vez alcanzada la temperatura se dejará que funcione por cierto tiempo, con una alerta si llega a salir del rango establecido para comprobar la estabilidad de la temperatura.
- Requerimiento 3: comprobar el seteo de la temperatura tanto como manual como inalámbrica
- Verificación: revisar que la temperatura mostrada en el display sea la misma que se seteo anteriormente.
- Validación: luego de setear una variable con dicha temperatura, se genera un sistema de control para llevarla al control de temperatura para mantener dicha temperatura. Cuando se consiga eso, se mandará la información al display para
- Requerimiento 4: evitar rupturas del filamento a la salida de la excursión
- Verificación: lograr que el plástico que se coloque quede solo un filamento y no varios por rupturas del mismo a la salida. Para eso se hará la excursión a una velocidad determinada.
- Validación: mirar que cuando termine el proceso solo se tengo un rollo de filamento y no 2.
- Requerimiento 5: conseguir el correcto funcionamiento del display mostrando la información necesaria
- Verificación: Comprobar que la información que da el display sea la correcta, como la conexión con el dispositivo como la temperatura establecida.
- Validación: Para lograr esto se comprobará el correcto funcionamiento de las demás cosas antes de realizar el display, así se obtiene el valor correcto.

Para este trabajo práctico, cómo se realiza con un grupo de trabajo de tres persona hay tareas que se van a atrasar por no tener demasiadas personas contratadas, debido que las personas se encuentran ocupadas por una tarea en paralelo. Por lo que el diagrama de gantt se modifica al mostrado en la Figura 7.1 dando la Figura 7.2.

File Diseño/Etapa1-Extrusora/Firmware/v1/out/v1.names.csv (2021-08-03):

TP-Prof/Diseño/Diseño-Electrico/Codigo-microcontrolador/v1/out/v1.elf:1a001a20 00000004 t InitClkStates
TP-Prof/Diseño/Diseño-Electrico/Codigo-microcontrolador/v1/out/v1.elf:1a001a24 00000074 t pinmuxing
TP-Prof/Diseño/Diseño-Electrico/Codigo-microcontrolador/v1/out/v1.elf:1a000484 00000044 t Board_LED_Init
TP-Prof/Diseño/Diseño-Electrico/Codigo-microcontrolador/v1/out/v1.elf:1a0004c8 00000040 t Board_TEC_Init
TP-Prof/Diseño/Diseño-Electrico/Codigo-microcontrolador/v1/out/v1.elf:1a000508 00000040 t Board_GPIO_Init
TP-Prof/Diseño/Diseño-Electrico/Codigo-microcontrolador/v1/out/v1.elf:1a000548 00000030 t Board_ADC_Init
TP-Prof/Diseño/Diseño-Electrico/Codigo-microcontrolador/v1/out/v1.elf:1a000578 00000038 t Board_SPI_Init
TP-Prof/Diseño/Diseño-Electrico/Codigo-microcontrolador/v1/out/v1.elf:1a0005b0 00000024 t Board_I2C_Init
TP-Prof/Diseño/Diseño-Electrico/Codigo-microcontrolador/v1/out/v1.elf:1a001a9c 00000008 t GpioButtons
TP-Prof/Diseño/Diseño-Electrico/Codigo-microcontrolador/v1/out/v1.elf:1a001aa4 0000000c t GpioLeds
TP-Prof/Diseño/Diseño-Electrico/Codigo-microcontrolador/v1/out/v1.elf:1a001ab0 00000012 t GpioPorts
TP-Prof/Diseño/Diseño-Electrico/Codigo-microcontrolador/v1/out/v1.elf:1a000630 00000014 t Chip_SSP_GetClockIndex
TP-Prof/Diseño/Diseño-Electrico/Codigo-microcontrolador/v1/out/v1.elf:1a000644 00000018 t Chip_SSP_GetPeriphClockIndex
TP-Prof/Diseño/Diseño-Electrico/Codigo-microcontrolador/v1/out/v1.elf:10000000 00000038 d i2c
TP-Prof/Diseño/Diseño-Electrico/Codigo-microcontrolador/v1/out/v1.elf:1a000804 00000014 t Chip_ADC_GetClockIndex
TP-Prof/Diseño/Diseño-Electrico/Codigo-microcontrolador/v1/out/v1.elf:1a000818 00000032 t getClkDiv
TP-Prof/Diseño/Diseño-Electrico/Codigo-microcontrolador/v1/out/v1.elf:1a001ac8 00000048 t InitClkStates
TP-Prof/Diseño/Diseño-Electrico/Codigo-microcontrolador/v1/out/v1.elf:1a000a38 000000a0 t pll_calc_divs
TP-Prof/Diseño/Diseño-Electrico/Codigo-microcontrolador/v1/out/v1.elf:1a000ad8 0000010c t pll_get_frac
TP-Prof/Diseño/Diseño-Electrico/Codigo-microcontrolador/v1/out/v1.elf:1a000be4 0000004c t Chip_Clock_FindBaseClock
TP-Prof/Diseño/Diseño-Electrico/Codigo-microcontrolador/v1/out/v1.elf:1a000e58 00000022 t Chip_Clock_GetDivRate
TP-Prof/Diseño/Diseño-Electrico/Codigo-microcontrolador/v1/out/v1.elf:10000058 00000008 b audio_usb_pll_freq
TP-Prof/Diseño/Diseño-Electrico/Codigo-microcontrolador/v1/out/v1.elf:1a001b1c 0000006c t periph_to_base
TP-Prof/Diseño/Diseño-Electrico/Codigo-microcontrolador/v1/out/v1.elf:1a000fc4 0000002c t Chip_UART_GetIndex
TP-Prof/Diseño/Diseño-Electrico/Codigo-microcontrolador/v1/out/v1.elf:1a001b88 00000008 t UART_BClock
TP-Prof/Diseño/Diseño-Electrico/Codigo-microcontrolador/v1/out/v1.elf:1a001b90 00000008 t UART_PClock
TP-Prof/Diseño/Diseño-Electrico/Codigo-microcontrolador/v1/out/v1.elf:10000038 00000004 d ClockSpeed
TP-Prof/Diseño/Diseño-Electrico/Codigo-microcontrolador/v1/out/v1.elf:1a001174 00000034 t gpioObtainPinInit
TP-Prof/Diseño/Diseño-Electrico/Codigo-microcontrolador/v1/out/v1.elf:10000060 00000004 b callBackFuncParams
TP-Prof/Diseño/Diseño-Electrico/Codigo-microcontrolador/v1/out/v1.elf:10000068 00000008 b tickCounter
TP-Prof/Diseño/Diseño-Electrico/Codigo-microcontrolador/v1/out/v1.elf:10000070 00000004 b tickHookFunction
TP-Prof/Diseño/Diseño-Electrico/Codigo-microcontrolador/v1/out/v1.elf:1a00148c 0000000c t pwmInitTimers
TP-Prof/Diseño/Diseño-Electrico/Codigo-microcontrolador/v1/out/v1.elf:1a0014e4 00000034 t pwmAttach
TP-Prof/Diseño/Diseño-Electrico/Codigo-microcontrolador/v1/out/v1.elf:1a001518 0000001c t pwmDetach
TP-Prof/Diseño/Diseño-Electrico/Codigo-microcontrolador/v1/out/v1.elf:10000048 0000000b d AttachedPWMList
TP-Prof/Diseño/Diseño-Electrico/Codigo-microcontrolador/v1/out/v1.elf:1a001c80 0000000b t pwmMap
TP-Prof/Diseño/Diseño-Electrico/Codigo-microcontrolador/v1/out/v1.elf:1a001c8c 0000001c t SCTdataList
TP-Prof/Diseño/Diseño-Electrico/Codigo-microcontrolador/v1/out/v1.elf:10000074 00000004 b g_hUsb
TP-Prof/Diseño/Diseño-Electrico/Codigo-microcontrolador/v1/out/v1.elf:1a001cac t __init_array_end
TP-Prof/Diseño/Diseño-Electrico/Codigo-microcontrolador/v1/out/v1.elf:1a001ca8 b __preinit_array_end
TP-Prof/Diseño/Diseño-Electrico/Codigo-microcontrolador/v1/out/v1.elf:1a001ca8 t __init_array_start
TP-Prof/Diseño/Diseño-Electrico/Codigo-microcontrolador/v1/out/v1.elf:1a001ca8 b __preinit_array_start
TP-Prof/Diseño/Diseño-Electrico/Codigo-microcontrolador/v1/out/v1.elf:1a000c7c 0000001c T Chip_Clock_GetDividerSource
TP-Prof/Diseño/Diseño-Electrico/Codigo-microcontrolador/v1/out/v1.elf:1a0001ba 00000002 W TIMER2_IRQHandler
TP-Prof/Diseño/Diseño-Electrico/Codigo-microcontrolador/v1/out/v1.elf:1a000184 00000002 W DebugMon_Handler
TP-Prof/Diseño/Diseño-Electrico/Codigo-microcontrolador/v1/out/v1.elf:1a0001ba 00000002 W RIT_IRQHandler
TP-Prof/Diseño/Diseño-Electrico/Codigo-microcontrolador/v1/out/v1.elf:1a080000 A __top_MFlashA512
TP-Prof/Diseño/Diseño-Electrico/Codigo-microcontrolador/v1/out/v1.elf:1a0001ba 00000002 W ADCHS_IRQHandler
TP-Prof/Diseño/Diseño-Electrico/Codigo-microcontrolador/v1/out/v1.elf:1a000114 T __section_table_start
TP-Prof/Diseño/Diseño-Electrico/Codigo-microcontrolador/v1/out/v1.elf:1a0001ba 00000002 W FLASH_EEPROM_IRQHandler
TP-Prof/Diseño/Diseño-Electrico/Codigo-microcontrolador/v1/out/v1.elf:1a0001ba 00000002 W I2C0_IRQHandler
TP-Prof/Diseño/Diseño-Electrico/Codigo-microcontrolador/v1/out/v1.elf:1a000628 00000008 T __stdio_init
TP-Prof/Diseño/Diseño-Electrico/Codigo-microcontrolador/v1/out/v1.elf:1a00017a 00000002 W HardFault_Handler
TP-Prof/Diseño/Diseño-Electrico/Codigo-microcontrolador/v1/out/v1.elf:1a000000 A __vectors_start__
TP-Prof/Diseño/Diseño-Electrico/Codigo-microcontrolador/v1/out/v1.elf:1a0008be 0000000c T Chip_ADC_SetResolution
TP-Prof/Diseño/Diseño-Electrico/Codigo-microcontrolador/v1/out/v1.elf:1a001460 0000002c T SysTick_Handler
TP-Prof/Diseño/Diseño-Electrico/Codigo-microcontrolador/v1/out/v1.elf:1a000344 00000002 W initialise_monitor_handles
TP-Prof/Diseño/Diseño-Electrico/Codigo-microcontrolador/v1/out/v1.elf:1a0001ba 00000002 W SDIO_IRQHandler
TP-Prof/Diseño/Diseño-Electrico/Codigo-microcontrolador/v1/out/v1.elf:1a0001ba 00000002 W ATIMER_IRQHandler
TP-Prof/Diseño/Diseño-Electrico/Codigo-microcontrolador/v1/out/v1.elf:1a000186 00000002 W PendSV_Handler
TP-Prof/Diseño/Diseño-Electrico/Codigo-microcontrolador/v1/out/v1.elf:1a000178 00000002 W NMI_Handler
TP-Prof/Diseño/Diseño-Electrico/Codigo-microcontrolador/v1/out/v1.elf:1a001cb4 R __exidx_end
TP-Prof/Diseño/Diseño-Electrico/Codigo-microcontrolador/v1/out/v1.elf:1a000150 T __data_section_table_end
TP-Prof/Diseño/Diseño-Electrico/Codigo-microcontrolador/v1/out/v1.elf:1a0001ba 00000002 W I2C1_IRQHandler
TP-Prof/Diseño/Diseño-Electrico/Codigo-microcontrolador/v1/out/v1.elf:1a0007f2 00000010 T Chip_SCT_Init
TP-Prof/Diseño/Diseño-Electrico/Codigo-microcontrolador/v1/out/v1.elf:1a0001ba 00000002 W UART1_IRQHandler
TP-Prof/Diseño/Diseño-Electrico/Codigo-microcontrolador/v1/out/v1.elf:1a0001ba 00000002 W GPIO5_IRQHandler
TP-Prof/Diseño/Diseño-Electrico/Codigo-microcontrolador/v1/out/v1.elf:1a0001ba 00000002 W CAN1_IRQHandler
TP-Prof/Diseño/Diseño-Electrico/Codigo-microcontrolador/v1/out/v1.elf:53ff7546 A __valid_user_code_checksum
TP-Prof/Diseño/Diseño-Electrico/Codigo-microcontrolador/v1/out/v1.elf:1a001cb4 R _etext
TP-Prof/Diseño/Diseño-Electrico/Codigo-microcontrolador/v1/out/v1.elf:1a0001ba 00000002 W USB1_IRQHandler
TP-Prof/Diseño/Diseño-Electrico/Codigo-microcontrolador/v1/out/v1.elf:1a0001ba 00000002 W I2S0_IRQHandler
TP-Prof/Diseño/Diseño-Electrico/Codigo-microcontrolador/v1/out/v1.elf:1a0001ba 00000002 W TIMER3_IRQHandler
TP-Prof/Diseño/Diseño-Electrico/Codigo-microcontrolador/v1/out/v1.elf:1a000efa 0000000c T Chip_Clock_GetBaseClocktHz
TP-Prof/Diseño/Diseño-Electrico/Codigo-microcontrolador/v1/out/v1.elf:1a0001ba 00000002 W UART0_IRQHandler
TP-Prof/Diseño/Diseño-Electrico/Codigo-microcontrolador/v1/out/v1.elf:1a0001a8 00000012 T bss_init
TP-Prof/Diseño/Diseño-Electrico/Codigo-microcontrolador/v1/out/v1.elf:1a0001ba 00000002 W SGPIO_IRQHandler
TP-Prof/Diseño/Diseño-Electrico/Codigo-microcontrolador/v1/out/v1.elf:1a0016c4 T __aeabi_uldivmod
TP-Prof/Diseño/Diseño-Electrico/Codigo-microcontrolador/v1/out/v1.elf:10000080 ? _noinit
TP-Prof/Diseño/Diseño-Electrico/Codigo-microcontrolador/v1/out/v1.elf:10000078 00000004 B SystemCoreClock
TP-Prof/Diseño/Diseño-Electrico/Codigo-microcontrolador/v1/out/v1.elf:1a000ff0 00000054 T Chip_UART_Init
TP-Prof/Diseño/Diseño-Electrico/Codigo-microcontrolador/v1/out/v1.elf:1a0001ba 00000002 W ADC0_IRQHandler
TP-Prof/Diseño/Diseño-Electrico/Codigo-microcontrolador/v1/out/v1.elf:1a000180 00000002 W UsageFault_Handler
TP-Prof/Diseño/Diseño-Electrico/Codigo-microcontrolador/v1/out/v1.elf:1a000f78 0000004c T Chip_Clock_GetRate
TP-Prof/Diseño/Diseño-Electrico/Codigo-microcontrolador/v1/out/v1.elf:1a0001ba 00000002 W GPIO6_IRQHandler
TP-Prof/Diseño/Diseño-Electrico/Codigo-microcontrolador/v1/out/v1.elf:1a00040c 0000006c T Board_SetupClocking
TP-Prof/Diseño/Diseño-Electrico/Codigo-microcontrolador/v1/out/v1.elf:20008000 A __top_RamAHB32
TP-Prof/Diseño/Diseño-Electrico/Codigo-microcontrolador/v1/out/v1.elf:1a0016f4 000002d0 T __udivmoddi4
TP-Prof/Diseño/Diseño-Electrico/Codigo-microcontrolador/v1/out/v1.elf:1a001a98 00000004 T ExtRateIn
TP-Prof/Diseño/Diseño-Electrico/Codigo-microcontrolador/v1/out/v1.elf:1a0001ba 00000002 W IntDefaultHandler
TP-Prof/Diseño/Diseño-Electrico/Codigo-microcontrolador/v1/out/v1.elf:1a000300 T __CRP_WORD_END__
TP-Prof/Diseño/Diseño-Electrico/Codigo-microcontrolador/v1/out/v1.elf:1a0015b0 0000004c T Sct_EnablePwmFor
TP-Prof/Diseño/Diseño-Electrico/Codigo-microcontrolador/v1/out/v1.elf:1a0001ba 00000002 W GPIO1_IRQHandler
TP-Prof/Diseño/Diseño-Electrico/Codigo-microcontrolador/v1/out/v1.elf:1a0001ba 00000002 W SSP0_IRQHandler
TP-Prof/Diseño/Diseño-Electrico/Codigo-microcontrolador/v1/out/v1.elf:1a001cac R __exidx_start
TP-Prof/Diseño/Diseño-Electrico/Codigo-microcontrolador/v1/out/v1.elf:1a0002fc 00000004 T CRP_WORD
TP-Prof/Diseño/Diseño-Electrico/Codigo-microcontrolador/v1/out/v1.elf:1a0019c8 00000048 T __libc_init_array
TP-Prof/Diseño/Diseño-Electrico/Codigo-microcontrolador/v1/out/v1.elf:1a0001ba 00000002 W ADC1_IRQHandler
TP-Prof/Diseño/Diseño-Electrico/Codigo-microcontrolador/v1/out/v1.elf:1a001558 00000024 T Sct_Init
TP-Prof/Diseño/Diseño-Electrico/Codigo-microcontrolador/v1/out/v1.elf:1a0005f8 00000030 T Board_Init
TP-Prof/Diseño/Diseño-Electrico/Codigo-microcontrolador/v1/out/v1.elf:1a0003d2 00000002 W _init
TP-Prof/Diseño/Diseño-Electrico/Codigo-microcontrolador/v1/out/v1.elf:1a000114 T __data_section_table
TP-Prof/Diseño/Diseño-Electrico/Codigo-microcontrolador/v1/out/v1.elf:1a0001ba 00000002 W RTC_IRQHandler
TP-Prof/Diseño/Diseño-Electrico/Codigo-microcontrolador/v1/out/v1.elf:10000080 B _ebss
TP-Prof/Diseño/Diseño-Electrico/Codigo-microcontrolador/v1/out/v1.elf:1a0001ba 00000002 W TIMER0_IRQHandler
TP-Prof/Diseño/Diseño-Electrico/Codigo-microcontrolador/v1/out/v1.elf:1a000348 00000088 T Reset_Handler
TP-Prof/Diseño/Diseño-Electrico/Codigo-microcontrolador/v1/out/v1.elf:1a0013e4 0000007c T tickInit
TP-Prof/Diseño/Diseño-Electrico/Codigo-microcontrolador/v1/out/v1.elf:20010000 A __top_RamAHB_ETB16
TP-Prof/Diseño/Diseño-Electrico/Codigo-microcontrolador/v1/out/v1.elf:1a0001ba 00000002 W SPI_IRQHandler
TP-Prof/Diseño/Diseño-Electrico/Codigo-microcontrolador/v1/out/v1.elf:1a000728 0000004a T Chip_SCTPWM_SetRate
TP-Prof/Diseño/Diseño-Electrico/Codigo-microcontrolador/v1/out/v1.elf:1a0007b8 00000038 T Chip_I2C_SetClockRate
TP-Prof/Diseño/Diseño-Electrico/Codigo-microcontrolador/v1/out/v1.elf:1a0001ba 00000002 W LCD_IRQHandler
TP-Prof/Diseño/Diseño-Electrico/Codigo-microcontrolador/v1/out/v1.elf:1a000c30 0000004c T Chip_Clock_EnableCrystal
TP-Prof/Diseño/Diseño-Electrico/Codigo-microcontrolador/v1/out/v1.elf:10008000 A __top_RamLoc32
TP-Prof/Diseño/Diseño-Electrico/Codigo-microcontrolador/v1/out/v1.elf:1a00018a 0000001e T data_init
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

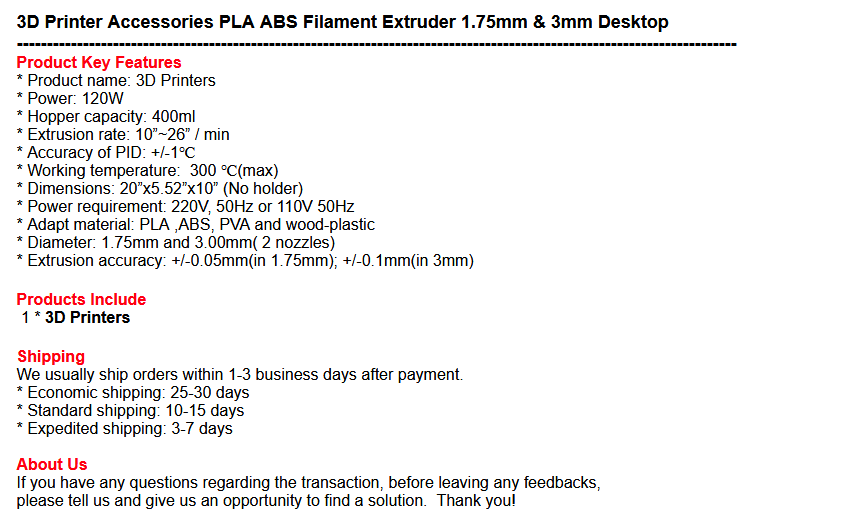
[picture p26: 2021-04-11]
Informacion-Equipos-Comerciales/ebay/especificaciones2.png

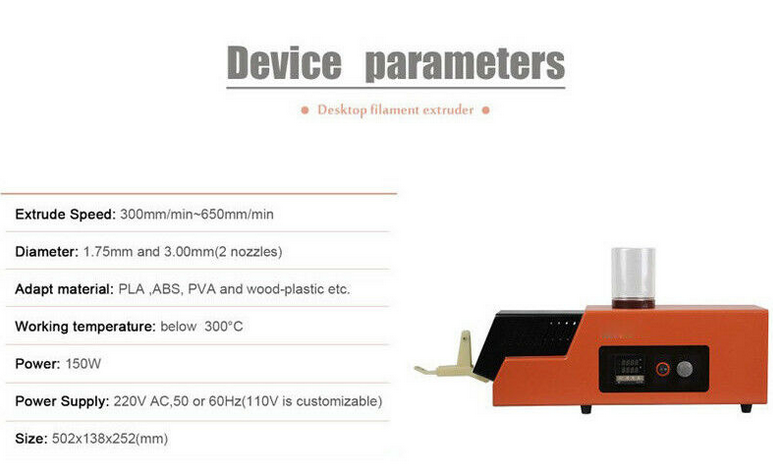
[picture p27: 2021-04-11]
Informacion-Equipos-Comerciales/ebay/especificaciones1.png

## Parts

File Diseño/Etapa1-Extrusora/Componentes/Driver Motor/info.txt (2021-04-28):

Opcion 1: Diseñarlo

Opcion 2: comprarlo para eso dejo una lista 

Link:https://articulo.mercadolibre.com.ar/MLA-616286235-doble-puente-h-driver-l298n-motor-dc-arduino-arm-avr-l298-_JM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

precio: $ 384.66 ARS

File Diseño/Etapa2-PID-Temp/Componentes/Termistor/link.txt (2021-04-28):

Link: https://articulo.mercadolibre.com.ar/MLA-879943706-termistor-100-k-ohm-con-cable-y-ficha-printalot-_JM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

Precio: $179 ARS

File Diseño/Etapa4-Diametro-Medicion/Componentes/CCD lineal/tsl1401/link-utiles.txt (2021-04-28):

## Donde comprar:

https://articulo.mercadolibre.com.ar/MLA-896434512-modulo-sensor-ccd-arduino-tsl1401-lineal-array-_JM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

Precio: $6000 arg -----> ver si se consigue mas barato

Creo que conviene tener dos para cada uno de los ejes pero con uno deberia bastar.

## Explicación y diferencia con una CCD Area:

link: https://programmerclick.com/article/24961539656/

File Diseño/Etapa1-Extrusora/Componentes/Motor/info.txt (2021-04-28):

Vamos a probar con uno de impresora continua sino vamos a usar uno mas potente. 

link: https://articulo.mercadolibre.com.ar/MLA-621095584-motor-micromotor-electrico-corriente-continua-para-modelismo-_JM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

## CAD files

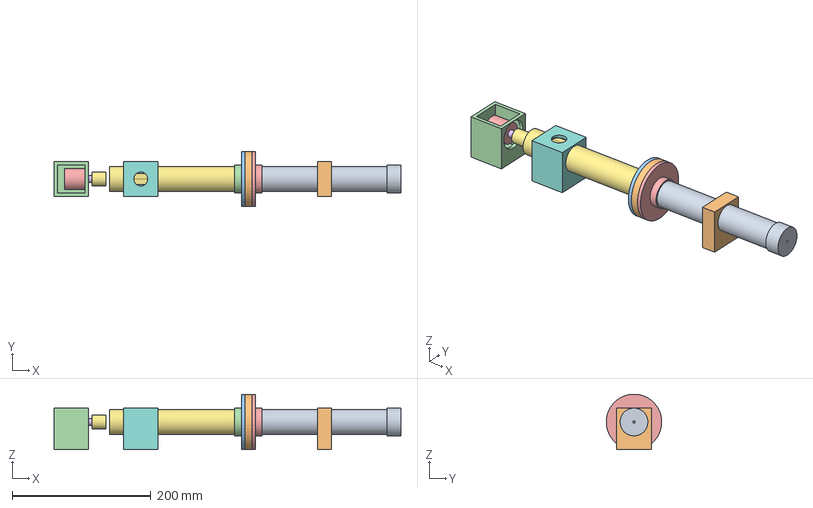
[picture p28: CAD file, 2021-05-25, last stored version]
Modelos/Modelo 1/modelo1.FCStd
500.0 x 80.0 x 79.9 mm
Tube001
Tube002
Tube003
Tube005
Cubo003
Cilindro005
Cilindro006
Cilindro007

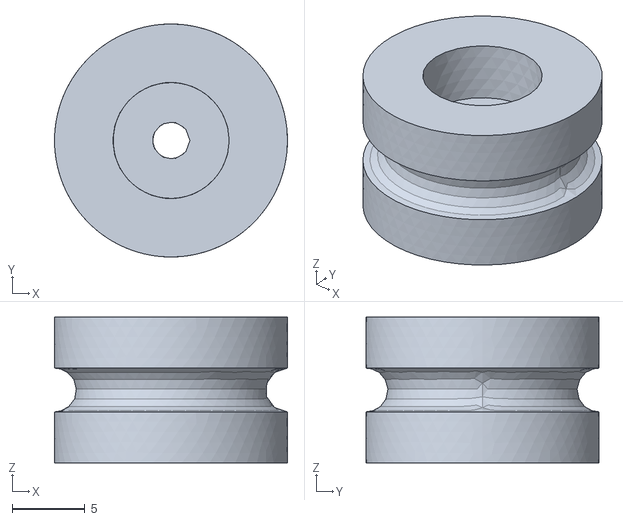
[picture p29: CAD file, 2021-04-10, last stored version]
Modelos/Piezas de un extraño 3D/puller_wheel.stl
16.0 x 16.0 x 10.0

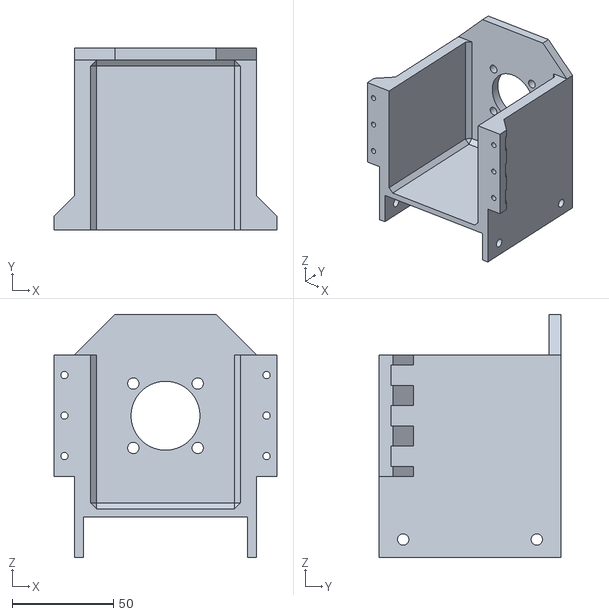
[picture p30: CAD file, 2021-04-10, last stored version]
Modelos/Piezas de un extraño 3D/motor_support.stl
110.0 x 90.0 x 120.0

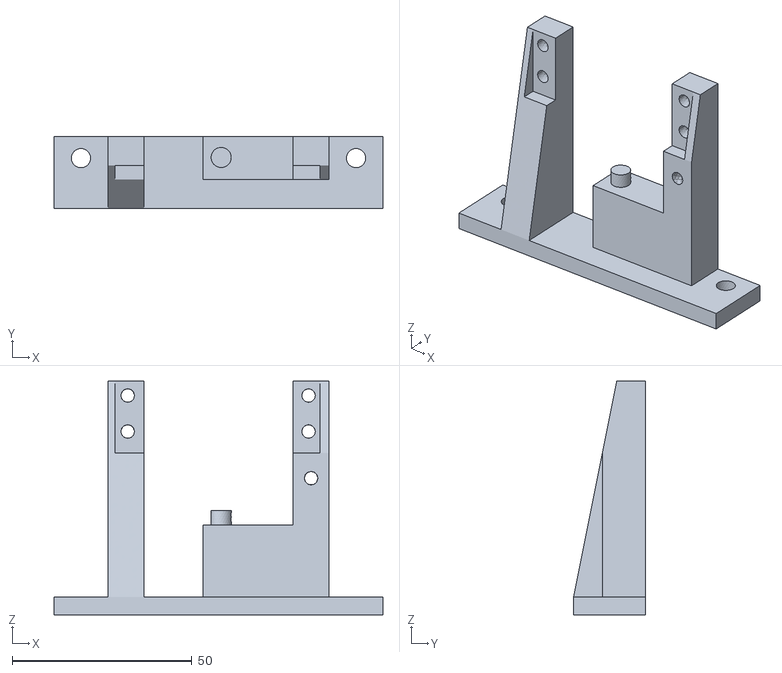
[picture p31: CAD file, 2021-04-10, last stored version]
Modelos/Piezas de un extraño 3D/puller_structure_simplified_fixed.stl
91.5 x 20.0 x 65.0

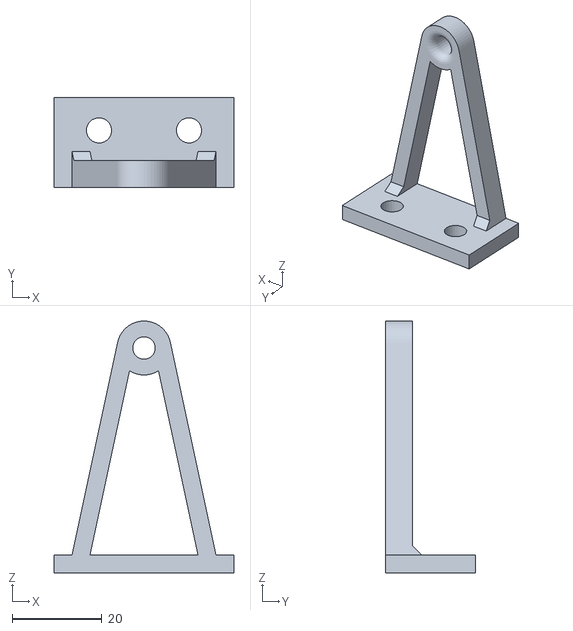
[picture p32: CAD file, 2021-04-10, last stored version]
Modelos/Piezas de un extraño 3D/filament_guide_smaller.stl
40.0 x 20.0 x 56.0

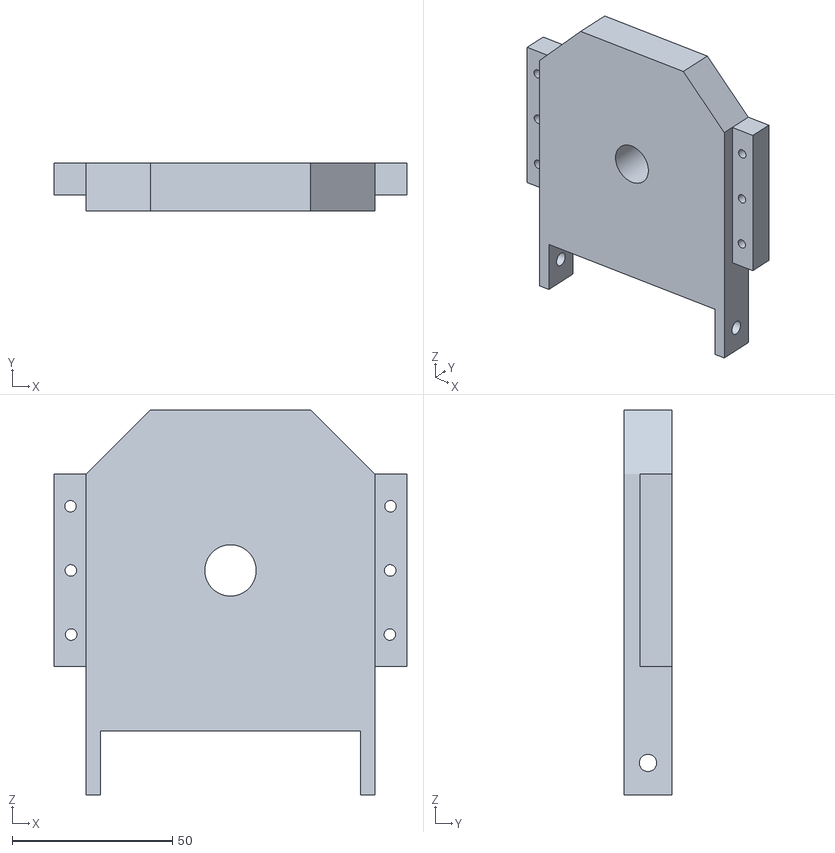
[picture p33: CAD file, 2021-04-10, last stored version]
Modelos/Piezas de un extraño 3D/thrust_bearing_support.stl
110.0 x 15.0 x 120.0

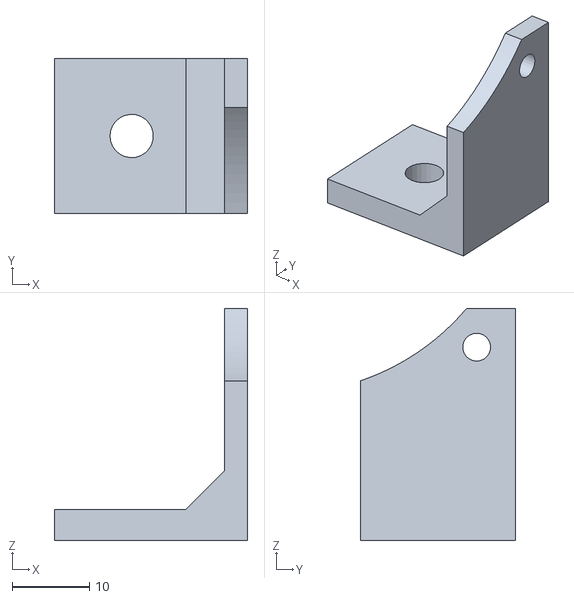
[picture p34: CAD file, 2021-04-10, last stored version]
Modelos/Piezas de un extraño 3D/fan_holder_left.stl
25.0 x 20.0 x 30.0

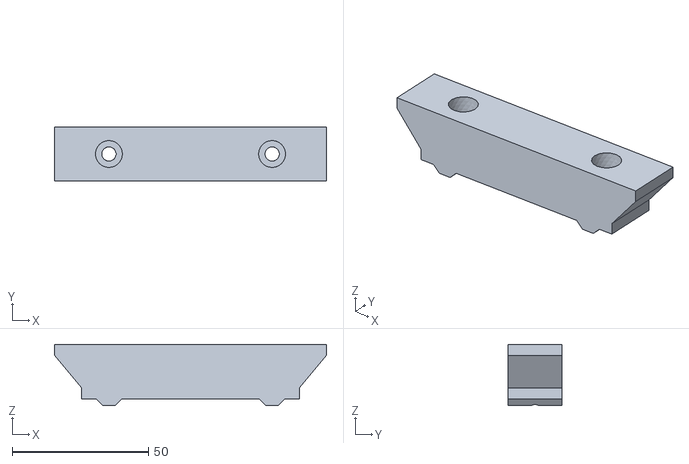
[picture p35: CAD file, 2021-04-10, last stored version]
Modelos/Piezas de un extraño 3D/vslot_foot.stl
100.0 x 20.0 x 22.5

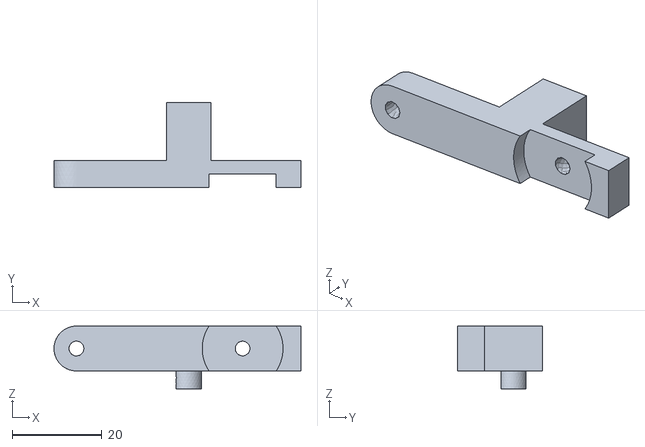
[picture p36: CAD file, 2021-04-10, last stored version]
Modelos/Piezas de un extraño 3D/puller_lever_with_spring.stl
55.0 x 19.0 x 14.0

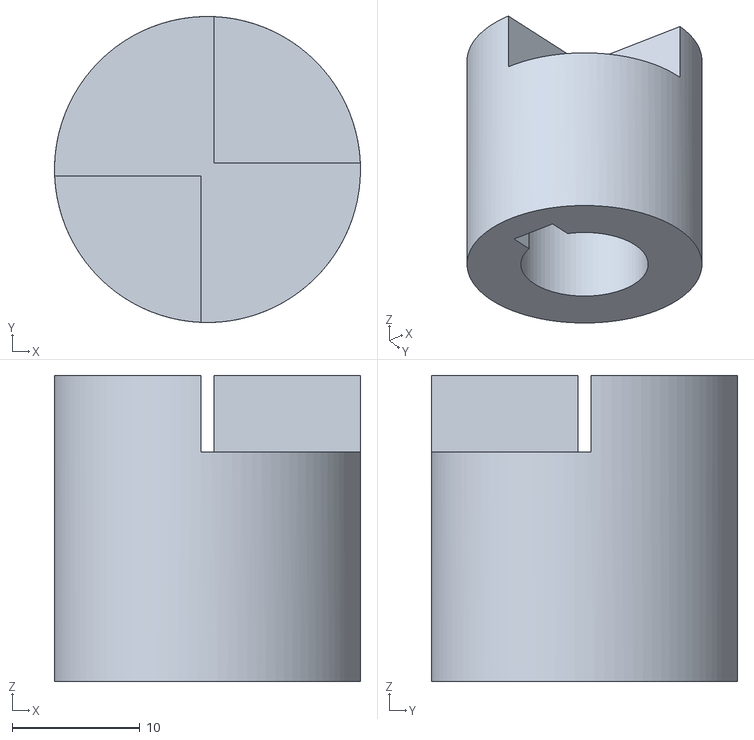
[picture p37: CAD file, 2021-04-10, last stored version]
Modelos/Piezas de un extraño 3D/shaft_coupler_keyway.stl
24.0 x 24.0 x 24.0

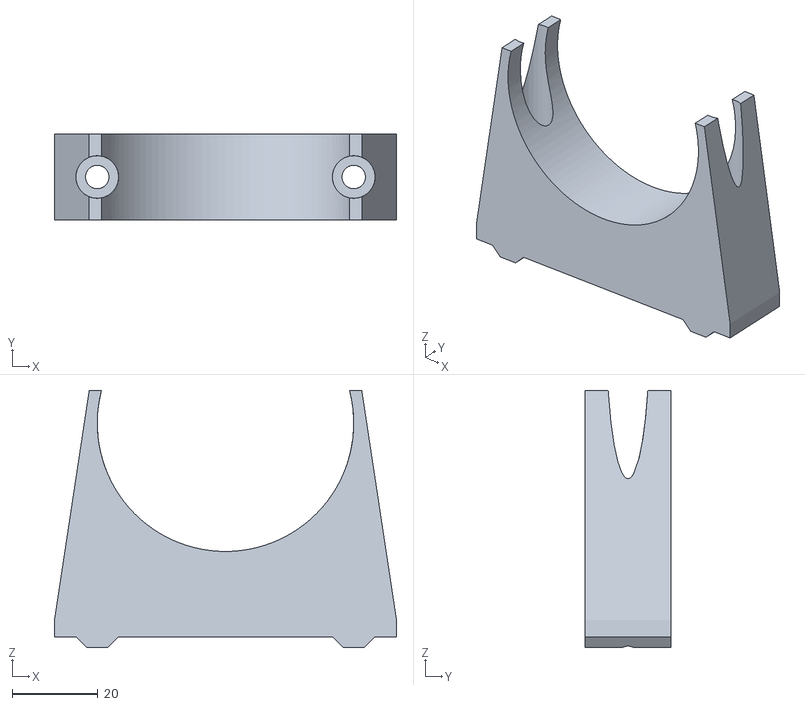
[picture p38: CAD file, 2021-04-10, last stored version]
Modelos/Piezas de un extraño 3D/vslot_motor_support_big.stl
80.0 x 20.0 x 60.2

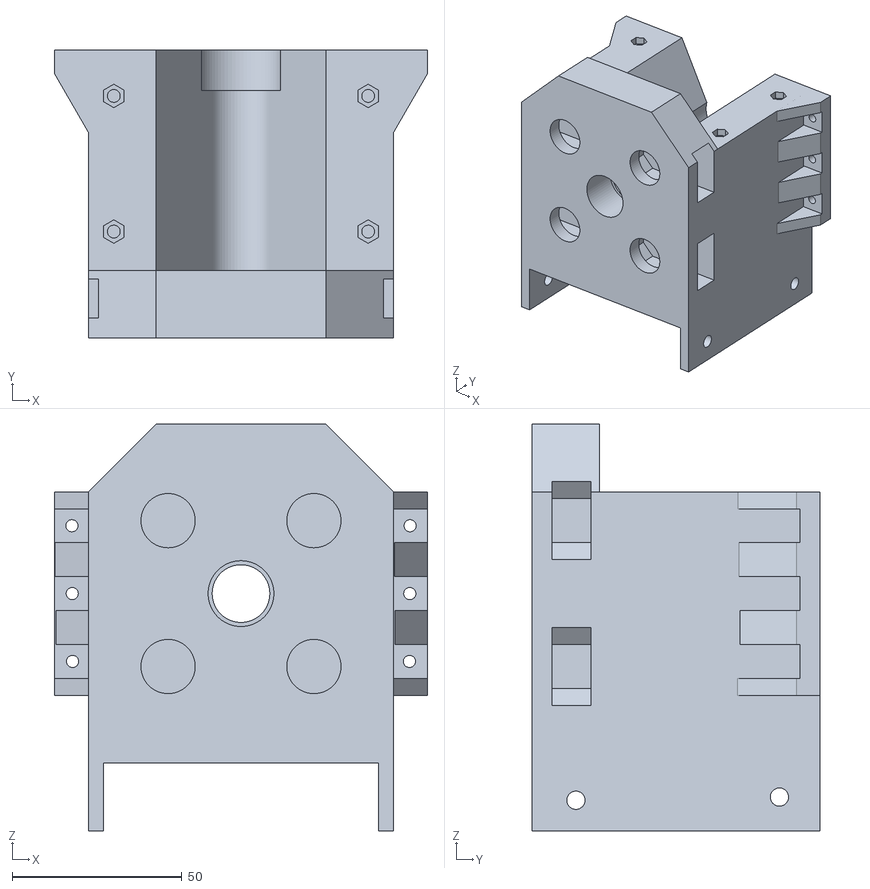
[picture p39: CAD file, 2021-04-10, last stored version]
Modelos/Piezas de un extraño 3D/hopper_and_barrel_support.stl
110.0 x 85.0 x 120.0

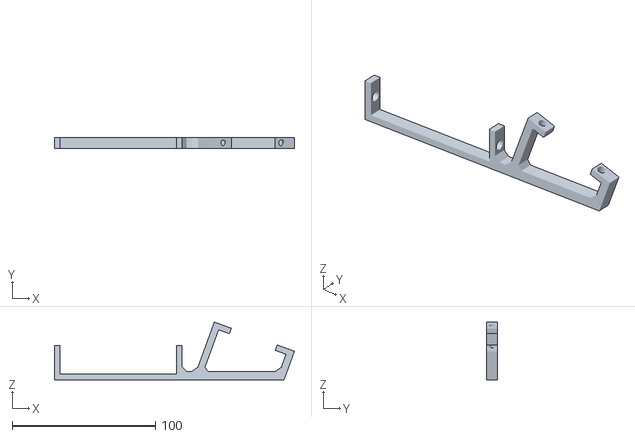
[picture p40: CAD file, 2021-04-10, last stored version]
Modelos/Piezas de un extraño 3D/lcd_holder.stl
167.5 x 8.00 x 40.4

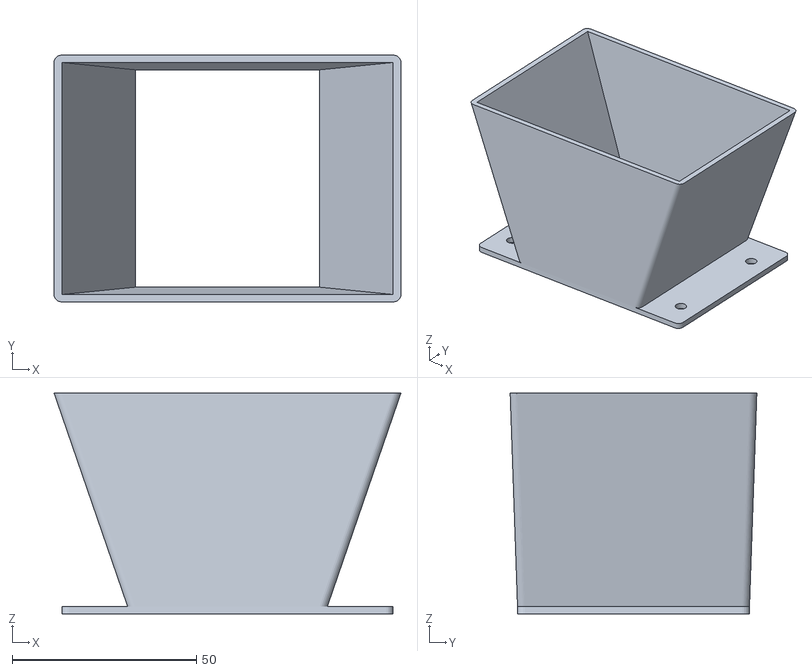
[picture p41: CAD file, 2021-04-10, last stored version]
Modelos/Piezas de un extraño 3D/hopper.stl
94.2 x 67.0 x 60.0

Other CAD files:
Modelos/Piezas de un extraño 3D/fan_holder_right.stl
Modelos/Piezas de un extraño 3D/shaft_coupler_hex.stl

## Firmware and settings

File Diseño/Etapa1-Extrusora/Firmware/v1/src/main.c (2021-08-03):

/* Copyright 2016, Eric Pernia.
 * All rights reserved.
 *
 * This file is part sAPI library for microcontrollers.
 *
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
 * 3. Neither the name of the copyright holder nor the names of its
 *    contributors may be used to endorse or promote products derived from this
 *    software without specific prior written permission.
 *
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
 */

/*
 * Date: 2016-04-26
 */

/*==================[inclusions]=============================================*/

#include "sapi.h"       // <= sAPI header

/*==================[macros and definitions]=================================*/

/*==================[internal data declaration]==============================*/

/*==================[internal functions declaration]=========================*/

/*==================[internal data definition]===============================*/

/*==================[external data definition]===============================*/

/*==================[internal functions definition]==========================*/

/*==================[external functions definition]==========================*/

/* FUNCION PRINCIPAL, PUNTO DE ENTRADA AL PROGRAMA LUEGO DE RESET. */
int main(void){

   /* ------------- INICIALIZACIONES ------------- */

   /* Inicializar la placa */
   boardConfig();
   uint8_t  dutyCycle1 = 128;
   /* configuaracion del pwm motor */


   uint8_t pwmVal = 0; /* 0 a 255 */

   pwmConfig( 0, PWM_ENABLE );
   pwmConfig( PWM1, PWM_ENABLE_OUTPUT );

   /* Usar PWM */
   pwmWrite( PWM1, dutyCycle1 );


   /* ------------- REPETIR POR SIEMPRE ------------- */
   while(1) {

      /* Prendo el led azul */
      gpioWrite( LEDR, ON );

      delay(500);

      /* Apago el led azul */
      gpioWrite( LEDR, OFF );

      delay(500);
   }

   /* NO DEBE LLEGAR NUNCA AQUI, debido a que a este programa no es llamado
      por ningun S.O. */
   return 0 ;
}

/*==================[end of file]============================================*/

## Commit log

2021-04-05 Hago un primer commit para subir los cambios sobre el README, explico un poco el manejo de github y la distribucion de carpetas del repo. Toda esta informacion se encuentra en el archivo README.md
2021-04-10 agrego un par de cosas que tenia
    [fan_holder_left.stl, fan_holder_right.stl, filament_guide_smaller.stl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]
2021-04-11 Especificaciones de productos comerciales
2021-04-15 Agrego el link de overleaf al readme
2021-04-28 actualizo el repo
2021-05-25 agrego el modelo
    [modelo1.FCStd]
2021-05-27 agrego las informe de embebidos
2021-05-27 agrego algunas imagenes del tp de embebidos
2021-08-03 organizacion de carpetas
    [fan_holder_left.stl, fan_holder_right.stl, filament_guide_smaller.stl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]
2021-08-07 actualizacion de carpetas
    [v1.names.csv]
